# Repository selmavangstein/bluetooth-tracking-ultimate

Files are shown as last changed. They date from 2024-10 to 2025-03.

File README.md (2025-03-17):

# Evaluating Methods for Radio Frequency Based Positioning of Ultimate Frisbee Players

## Abstract
We developed a bluetooth system for tracking ultimate frisbee players. Our project was centered around:
- Exploring different technologies
- Creating and optimizing physical implementations of the best technologies (FTM and UWB), complete with beacons, mounts, and wearables
- Process and analyze the data to make it cleaner and more accurate

This repo contains active, final implementations of data processing and analysis including the data pipeline and the ground truth system, in addition to Arduino and CAD files for the physical implementations. 

### Contributors

| Name | Email |
| --- | --- |
| Cullen Baker | bakerc2@carleton.edu |
| Will Shrestha | shresthaw@carleton.edu |
| Selma Vangstein | vangsteins@carleton.edu |
| Sam Diana  | dianas@carleton.edu |
| Marshall Johnson  | johnsonm@carleton.edu |
| Bemnet Abebayehu  | abebayehub@carleton.edu |

## Contents

- [Abstract](#abstract)
- [How to use](#how-to-use)
- [Project Structure](#project-structure)
- [Data Processing overview](#data-processing-overview)
- [Ground Truth Overview](#ground-truth-overview)
- [Wearable and Beacon Overview](#wearable-and-beacon-overview)
- [Future Work](#future-work)
- [Acknowledgements](#acknowledgements)

## How to use
Simply run `final-postprocessing-pipeline.py` on your desired data by editing the test file names within main, and it will apply the processing steps one piece at a time. 

## Project Structure

To navigate through our codebase, follow the steps below:

1. **Data Creation:**
   Using Code uploaded to a UWB or FTM module from the Arduino IDE, and boosted, powered, held, and added to (accelerometers) with our physical setup, we extract raw data files in `.log` format.

2. **Data Input:**
- These raw data files (in `.log` format) contain distance measurements from the player to each beacon.
- Example files: `rawdataexample.log` (raw data) and `rawdataexample.csv` (processed data).
- All data is stored under the `data/` folder.

3. **Data Cleaning:**
- First, we clean and convert the raw data to a CSV format for easier processing. The folder `data/` contains both ground truth data and processed data files for various days tests were conducted.

4. **Post-Processing Pipeline:**
- Once our data is retrieved and in our desired format, we process the data through various cleaning algorithms in this order:
    - **Distance Correction**
    - **Outlier Removal**
    - **Velocity Clamping**
    - **Smoothing**
    - **Velocity Clamping**
- NOTE: More details for each algorithm above can be found undernearth [Data Processing overview](#data-processing-overview). 
- The `final-postprocessing-pipeline.py` file contains calls to each algorithm above that are sequentially applied to our dataframe. Each step is executed one after the other, and users can rearrange the order of algorithms to fit their needs.

5. **Final Processing:**
- After cleaning, the data is used to estimate player positions using trilateration, which can be found in `final-trilateration.py`.
- The cleaned coordinates are further refined using a Kalman filter. This is implemented in `Final-kalman.py`.
- NOTE: More details for the Kalman filter can be found underneath [Kalman filtering ](#kalman-filtering).

6. **Charts:**
- After the data has been processed, various charts are generated to visualize the effectiveness of each post-processing step. These charts are stored in the `charts/` folder.
- You will find:
    - Plots that show the behavior of the data before and after applying each algorithm.
    - An animation (MP4 video) under the name "streamlit" which visualizes the player’s path during the test.

7. **Frontend:**
- The `frontend.py` file contains a Streamlit-based web interface where you can visualize the results and generate PDF reports from the processed data.

## Data Processing overview
The data processing serves to move from raw testing data files containing distances from player to beacons, to a cleaned and refined dataset containing player coordinates over the duration of the test. 
The raw data generally has low noise levels and lies close to ground truth. It gets noisy whenever something is blocking the line-of-sight between player and beacon. The post processing aims to identify and handle these noisy areas to get accurate coordinate estimates. 
We now aim to walk through the steps in the pipeline. In broad strokes, we start by processing the 1D distance measurements to get rid of noise in the data. The steps in this process are applied in the order listed below, which is what we think is the best order, but the code enables a user to apply these in any order. We then use an alternative trilateration algorithm to determine player coordinates from the position measurements. Finally, we filter the coordinates.

### Distance Correction
We found a systematic overestimate of about 0.8 meters in our raw data, so we subtract this for our dataset. This might be different for different wearables, so in the future we recommend to test each sensor individually, and tune them individually.

### Outlier Removal
This algorithm aims to identify noisy areas and get rid of them. The algorithm is based on identifying deviations from a mean, and is biased towards deleting inflated/deflated measurements, because we notice that the sensors usually overestimates the distance whenever an obstacle is blocking the signal. 
We use a rolling window of 800 ms, and calculate a linear fit in this window. We then mark any window containing a datapoint that deviates more than 0.5 meter from this fitted line as a window containing an outlier. In windows flagged to contain an outlier, we then calculate the median of the window and take the difference of each data point against the median and if it deviates by more than half a meter in either +/- direction, targeting those large spikes, we exclude those points and create a fitted line with the remaining data points. We find that in blocks of noise, there are real data points that still lie close to the ground truth, and the noise causes spikes above this line. We therefore go through a second time in the same manner, calculating the median of the adjusted window, this time only flagging outliers above the fitted line that deviate by more than 0.5 meter in the + direction. We exclude those flagged points and return our fitted line with this newly adjusted window and replace the outliers with nan, unless the window is filled with noise - then we replace them with a point on the fitted line.

### Velocity Clamping
Frisbee players on a field can only move with a max velocity of about 11m/s. We use this to identify remaining outliers in the data. We loop over the data points, and calculate the difference in time and distance from the last valid neighbor. We use this to calculate the average velocity between the data points, and if this is too high, we flag the point as invalid. We keep doing this until no more invalid points are found. We then go through and replace the remaining points with nan.

We will now be left with some small 'floating' clusters of points surrounded by nan. When an obstacle is blocking the signal, we might get several consecutive inflated measurements, and these will not be caught by the velocity clamping. Because these smaller floating groups are probably also noise, we go through and delete them.

We recommend tuning the threshold for what a "small" group of points is, depending on the hardware in use, and where in the pipeline this step is applied. If it is applied on raw data, high variance in noisy areas means that many of these small groups are real values, and we want to be careful with deleting them. However, the outlier removal changes the characteristics of the dataset, and leaves wider bumps rather than narrow spikes in noisy areas, and we can therefore be a lot more aggressive with a higher threshold.

There is a question about whether it is best to simply delete, or try to replace the invalid points. Since we have data from four beacons, and only three are theoretically required to find a coordinate from distance measurements, we decided to delete the points. This way we are not feeding faulty measurements to the trilateration algorithm.

Lastly, note that there is a strong forward bias in this algorithm, meaning that it favours early data points over later ones. If we encounter a wide step representing noise, we might not be able to cut this whole step out. When the data then steps back down to the undisturbed measurements, it will mark the first clean values as invalid, because they have moved too fast away from the noisy step. In the future, it might be possible to also run the algorithm in the other direction, and use some combination of the marked data points to figure out which ones are truly invalid.

### Smoothing
The last thing we do to our distance measurements is to smooth them out. We use an EMA (exponential moving average) algorithm with a window of 15 data points. This window can be tuned in the future, but be cautious about making this window too large, since this will cause the data to lack behind ground truth. The players might be moving erratically, so the smoothing should not be very aggressive.

### Trilateration
The next step is to convert the distance measurements into player coordinates. Regular trilateration is very sensitive to erroneous measurements, so we developed our own algorithm. 
For each set of four distance measurements, we do the following:
- Draw a circle around each beacon corresponding to the measured beacon
- Mark all circle intersections
- Identify the densest cluster of circle intersections
- Find the centroid of this densest cluster. This is the final position coordinate.
- Use the distance between the coordinate and each circle to calculate a measurement error
This algorithm is more robust than regular trilateration - if one beacon measurement is off, it will not affect the final coordinate. We will also still be able to come up with a coordinate if some data is completely missing. 
We do this for each timestamp, and finally plot a player trace with the coordinates.

### Kalman Filtering
We now apply a Kalman filter to the coordinate dataset. We use a 6-state constant acceleration model, with (x,y)-position coordinates as the only measurement, and velocity and acceleration as hidden variables. 
A Kalman filter is essentially a cycle of predictions, measurements and weighted averages. The filter uses a constant acceleration model to use the previous measurement to predict what the next position will be. It then takes in the actual measured coordinates, and uses the uncertainties of the measurement and prediction to take a weighted average between the two, and this gives us the filtered coordinate. 
The repo we used, along with some really thorough documentation, can be found here: https://github.com/rlabbe/Kalman-and-Bayesian-Filters-in-Python

We also added some additional steps to the filter cycle:

#### Dynamic filter adjustment
We used the error estimation from the trilateration algorithm to dynamically adjust the filter as we go. If the coordinate error is too high, we inflated the measurement uncertainty, essentially telling the filter to mostly disregard the measurement, and trust the prediction instead.

#### Velocity and acceleration clamping
We then added a 2D-version of the velocity clamping from above. This time, we did not want gaps in our data, so whenever an invalid point was detected, we replaced it with a new point in the same direction, but closer to its neighbor. We also added another layer to this clamping, taking the current acceleration magnitude into account. This magnitude was calculated from the data we get from the accelerometer.

#### RTS Smoothing
The final step is to apply RTS Smoothing. This smoothing algorithm is implemented for us by the Kalman package. It work in essentially the same way as the Kalman filter, except for the fact that it runs backwards. This means that it uses the future datapoints to predict the previous ones, balancing out the forward bias the Kalman filter introduced.

## Ground Truth Overview
We recorded videos of our testing. Each video begins by looking at a phone that is on time.gov displaying the exact time. This allows us to match where the testing subject is in the video to the time of the outputted data. 

We used a couple different systems of actually obtaining the ground truth data for each timestamp, all of which are centered around Google Sheets and the distance between cones and beacons. One method is to assign grid coordinates to the cones, then use the distance between two points formula for each (works best when the path walked varies). Another is to precalculate the distance between each cone and each beacon and then copy it for each additional reading (works best when the path walked stays the same)

Our ground truth system is fundamentally imperfect as, since we have humans inputting ground truth data that has been matched to the second, each ground truth reading can vary by up to one second.

The ground truth data is then compared to the raw data and the processed data using GroundTruthPipeline.py.

The videos, Google Sheets files, raw data, and outputted ground truth can all be found in this repository. 

## Wearable and Beacon overview
We designed many different models of wearables and beacons for FTM and UWB, designed to fill different needs, including:
- comfort
- convenience
- protection
- minimal signal obstruction

We fully created and assembled numerous models.

## Future Work
In the future, we plan to implement multi-player functionality, as the system currently supports only single-player tracking. Additionally, we aim to enhance the frontend to include live statistical analysis and track more player metrics beyond just location. We also plan to improve the data processing algorithms, potentially utilizing machine learning-based outlier detection for more thorough and effective noise removal. Furthermore, we will hope to explore alternative hardware mechanisms and improve existing ones, such as FTM and UWB.

## Acknowledgements
We would like to thank our advisor Eric Alexander for all of the patience and help given to us throughout these past two terms. He has been instrumental in guiding us in completing our project. We would also like to thank Aaron Heidgerken-Greene for his assistance and help within the makerspace and constructions of our hardware. Please feel free to reach out to Eric Alexander for any questions or wants to work on this.

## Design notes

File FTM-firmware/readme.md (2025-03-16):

# FTM software
FTM was one of the first positioning technologies we seriously considered. This setup consists of beacons, a wearable, and a recorder beacon. The wearable device iterates through each of the beacons, connecting and taking an FTM measurement, before sending this and acceleration data via espnow to be recorded. 

## Required materials
For our implementation of FTM positioning, we're making use of 6x xiao esp32s3 boards. 4 will act as beacons, 1 will act as a wearable, and 1 will act as a "recorder beacon". This firmware is likely compatible with any esp32 that supports FTM ranging, but this has not been confirmed.

## Flashing boards
Before getting started, make sure you install the necessary dependencies via the Arduino IDE. You'll need Wire, adafruit Sensor, and adafruit ADXL345_U.

Start by flashing the recorder beacon board; you'll need to make sure that you acquire the MAC address for this board, or else the wearable will not be able to communicate with it. This device will send data it receives via a serial-usb connection.

Your wearable board will simply need to be flashed with the provided sketch, after modifying the espNow receiver address. See the recorder_beacon sketch for more details on the mac address retrieval process. Please also ensure that the ADXL345 accelerometer is wired correctly, as a failure to do so can cause unpredictable issues.

To flash beacons, make sure that you change the beacon's address to one of the 4 provided ANCHOD_ADD values (such that there is one of each). Note that if you do change the address of an anchor, you'll also need to modify the switch found in the wearable.

## Common Issues
Make sure that you've enabled USE-CDC-ONBOOT (in the arduino ide) for any device you intend to print over serial. 

Make sure that you have the correct board selected, otherwise pin assignment/other issues might occur.

Ensure that your accelerometer is producing values; try using one of Adafruit's example sketches. Failure to do so can cause issues down the line.

Make sure that you have the correct MAC address of your recorder beacon, and have correctly input this into the wearable's firmware. Otherwise, the connection will fail and you won't be able to collect data.

Make sure each beacon has a unique network name, and that any changes you make to your beacon names are also reflected in your wearable firmware.

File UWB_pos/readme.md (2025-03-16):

# UWB software
For its accuracy and sampling rate, UWB represented one of the best options we found thus far. For our experiments, we utilized dw1000 boards. By default, this software also utilizes espnow to extract data. The recorder beacon software is identical for FTM, thus the sketch found in the FTM-firmware can be used.

## Required materials
For our implementation of UWB positioning, we're making use of 5xMakerfabs UWB-esp32 boards and another that supports espNow. 4 will act as beacons(to use UWB terminology, anchor), 1 will act as a wearable (tag), and 1 will act as a recorder beacon. You will also need an ADXL345 accelerometer, connected to the default i2c pins of your board.

## Flashing boards
Before getting started, make sure you install the necessary dependencies via the Arduino IDE. Notably, we built using makerfabs provided driver (based off the original, Thotro driver)

Your wearable board will simply need to be flashed with the provided sketch, after modifying the espNow receiver address. See the recorder_beacon sketch in FTM-firmware for more details on the mac address retrieval process. Please also ensure that the ADXL345 accelerometer is wired correctly, as a failure to do so can cause unpredictable issues.

To flash beacons, make sure that you change the beacon's address to one of the 4 provided ANCHOD_ADD values (such that there is one of each). Note that if you do change the address of an anchor, you'll also need to modify the switch found in the wearable.

## Common issues
Make sure that you've enabled USE-CDC-ONBOOT (in the arduino ide) for any device you intend to print over serial. 

Make sure that you have the correct board selected, otherwise pin assignment/other issues might occur. The makerfabs boards just work with the "ESP32 Dev Module" setting.

Ensure that your accelerometer is producing values; try using one of Adafruit's example sketches. Failure to do so can cause issues down the line.

Make sure that you have the correct MAC address of your recorder beacon, and have correctly input this into the wearable's firmware. Otherwise, the connection will fail and you won't be able to collect data.

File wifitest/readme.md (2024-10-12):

A simple test program for the s2 (although should be pretty universally compatible). Connects to my phone, and prints current signal level over serial.

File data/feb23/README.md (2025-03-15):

# Descriptions for Tests from February 23

## aroundsquare
In this test, we had a tester wear the UWB wearable on their head and walk inside the rec between adjacent cones in a 3x3 grid of cones that are each 3 meters apart.

### aroundsquare-groundtruth.csv
Ground truth data.

### aroundsquare-uwb.csv
Data from the UWB wearable.

## diagonals
In this test, we used the same setup as the previous test but the tester walked to diagonal cones as well as adjacent cones

### diagonals-groundtruth.csv
Ground truth data.

### diagonals-uwb.csv
Data from the UWB wearable.

## Test locations in coordinates (m)
Beacon 1: (0, 0)
Beacon 2: (28.7, 0)
Beacon 3: (28.7, 25.7)
Beacon 4: (0, 25.7)
Top left cone: (11.35, 15.85)
Top center cone: (14.35, 15.85)
Top right cone: (17.35, 15.85)
Middle left cone: (11.35, 12.85)
Middle center cone: (14.35, 12.85)
Middle right cone: (17.35, 12.85)
Bottom left cone: (11.35, 9.85)
Bottom center cone: (14.35, 9.85)
Bottom right cone: (17.35, 9.85)

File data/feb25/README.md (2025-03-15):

# Descriptions for Tests from February 25

## abovehead
In this test, we had a tester hold the wearable above their head and walk inside the rec between adjacent and diagonal cones in a 3x3 grid of cones that are each 3 meters apart.

### abovehead-groundtruth.csv
Ground truth data.

### abovehead-uwb.csv
Data from the UWB wearable.

## blockingbeacon
In this test, we had a tester wear the UWB wearable on their head and walk inside the rec between adjacent cones in a 3x3 grid of cones that are each 3 meters apart.
We also had another person standing in front of Beacon 1 as an obstacle.

### blockingbeacon-groundtruth.csv
Ground truth data.

### blockingbeacon-uwb.csv
Data from the UWB wearable.

## markingtest
In this test, we had a tester wear the UWB wearable on their head and walk inside the rec between adjacent cones in a 3x3 grid of cones that are each 3 meters apart.
We also had another person following the tester closely and staying between the wearable and Beacon 1 as an obstacle.

### markingtest-groundtruth.csv
Ground truth data.

### markingtest-uwb.csv
Data from the UWB wearable.

## Test locations in coordinates (m)
Beacon 1: (0, 0)
Beacon 2: (28.7, 0)
Beacon 3: (28.7, 25.7)
Beacon 4: (0, 25.7)
Top left cone: (11.35, 15.85)
Top center cone: (14.35, 15.85)
Top right cone: (17.35, 15.85)
Middle left cone: (11.35, 12.85)
Middle center cone: (14.35, 12.85)
Middle right cone: (17.35, 12.85)
Bottom left cone: (11.35, 9.85)
Bottom center cone: (14.35, 9.85)
Bottom right cone: (17.35, 9.85)

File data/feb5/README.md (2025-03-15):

# Descriptions for Tests from February 5

## obstacletest
In this test, we had a tester hold the UWB wearable and walk inside the rec from cone to cone in a 3x3 grid of cones that are each 3 meters apart. We also had someone stand
directly in front of Beacon 1 to act as an obstacle.

### obstacletest-groundtruth.csv
Ground truth data.

### obstacletest-uwb.csv
Data from the UWB wearable.

## Test locations in coordinates (m)
Beacon 1: (0, 0)
Beacon 2: (12, 0)
Beacon 3: (0, 18)
Beacon 4: (12, 18)
Top left cone: (3, 12)
Top center cone: (6, 12)
Top right cone: (9, 12)
Middle left cone: (3, 9)
Middle center cone: (6, 9)
Middle right cone: (9, 9)
Bottom left cone: (3, 6)
Bottom center cone: (6, 6)
Bottom right cone: (9, 6)

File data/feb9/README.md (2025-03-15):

# Descriptions for Tests from February 9

## linerectangle
In this test, we had a tester hold the FTM and UWB wearables and walk on the Anderson lawn in a straight line for 40 meters and then back, with additional turns on the way back
that form 5m x 10m rectangle in the middle of the straight line. Cones were placed every 5 meters on the 40 meter straight line and at each corner of the rectangle.

### linerectangle-ftm.csv
Data from the FTM wearable.

### linerectangle-groundtruth.csv
Ground truth data.

### linerectangle-uwb.csv
Data from the UWB wearable.

## Test locations in coordinates (m)
Beacon 1: (20, 0)
Beacon 2: (0, 0)
Beacon 3: (0, 40)
Beacon 4: (20, 40)
Straight line start: (10, 0)
Straight line far end: (10, 40)
Rectangle corner 1: (5, 20)
Rectangle corner 2: (5, 15)
Rectangle corner 3: (15, 15)
Rectangle corner 4: (15, 20)

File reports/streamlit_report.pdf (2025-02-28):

## Bluetooth Tracking Report

RF Positioning Report

February 27, 2025

1

## 1 1D b1d_distance

Figure 1: b1d Distance Over Time

2

## 2 1D b2d_distance

Figure 2: b2d Distance Over Time

3

## 3 1D b3d_distance

Figure 3: b3d Distance Over Time

4

## 4 1D b4d_distance

Figure 4: b4d Distance Over Time

5

## 5 streamlit

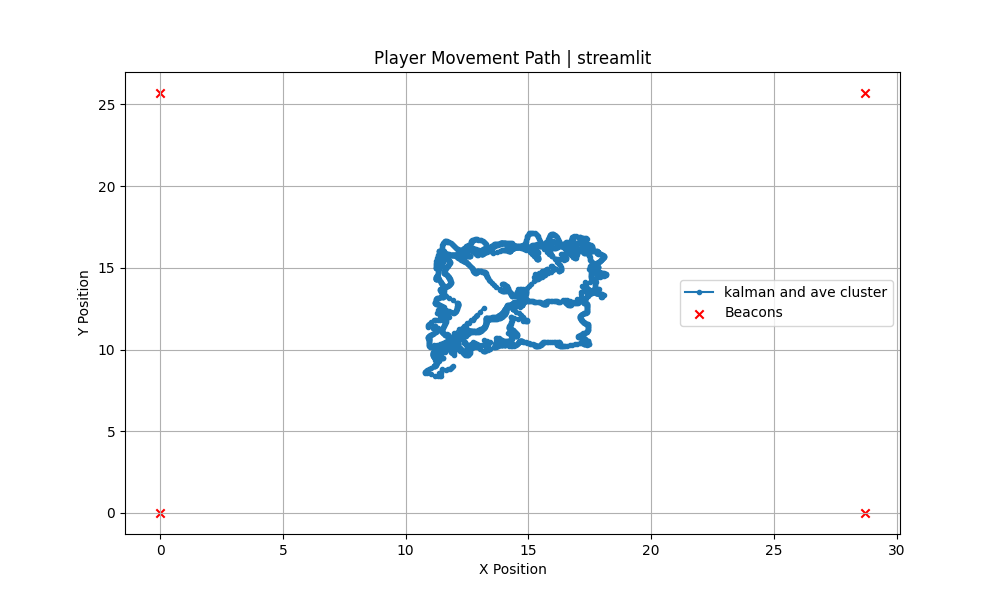
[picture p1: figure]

Figure 5: Final Player Movement Path

6

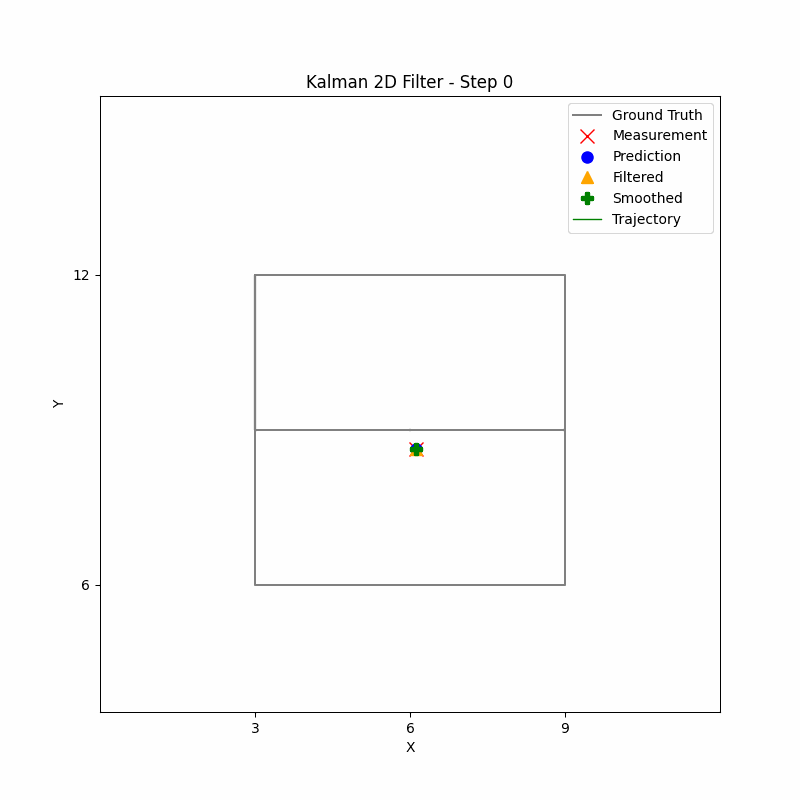
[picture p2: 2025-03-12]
kalman_animation_overhead.gif

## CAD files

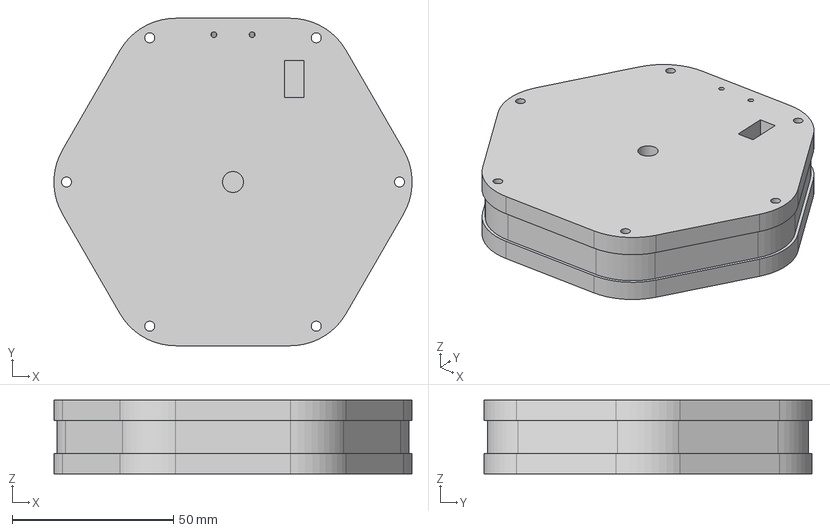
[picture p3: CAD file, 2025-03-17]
Wearables_and_Mounts/FTM_Mounts/FTM_beacon.step
111.1 x 101.6 x 22.9 mm
BOSS-EXTRUDE14_8_
BOSS-EXTRUDE7_4_
BOSS-EXTRUDE7_3_
BOSS-EXTRUDE14_4_
BOSS-EXTRUDE14_2_
BOSS-EXTRUDE14_11_
BOSS-EXTRUDE7_7_
BOSS-EXTRUDE14_9_
BOSS-EXTRUDE14_3_
BOSS-EXTRUDE14_7_
MIRROR2
BOSS-EXTRUDE14_5_
BOSS-EXTRUDE14_12_
BOSS-EXTRUDE7_8_
BOSS-EXTRUDE7_1_
BOSS-EXTRUDE14_10_
BOSS-EXTRUDE7_9_
BOSS-EXTRUDE14_6_
BOSS-EXTRUDE14_1_
BOSS-EXTRUDE7_6_
BOSS-EXTRUDE7_2_
CUT-EXTRUDE5
BOSS-EXTRUDE7_5_
Shield
Pins x 2
U.FL-R-SMT-1_10_ v1

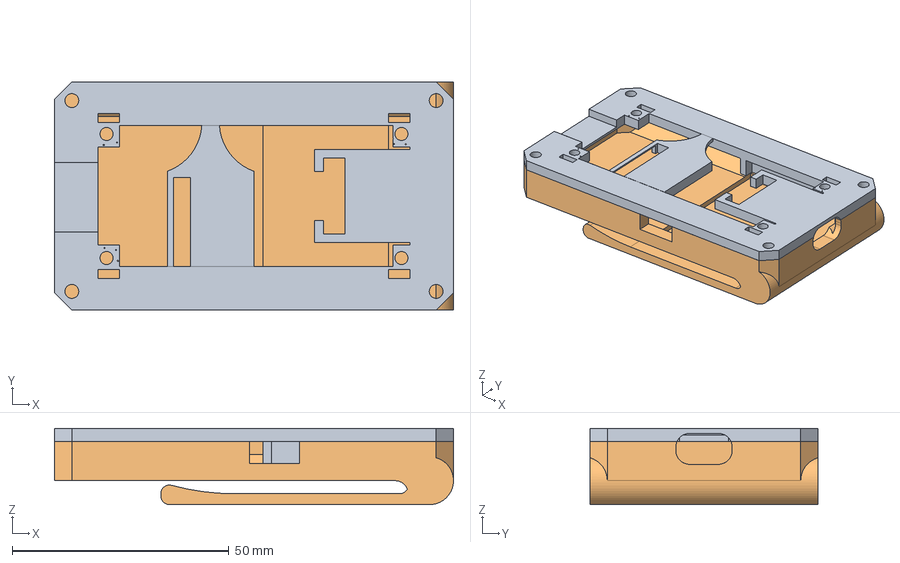
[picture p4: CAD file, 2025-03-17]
Wearables_and_Mounts/UWB_Mounts/UWB_clip_mount.step
92.0 x 52.6 x 17.6 mm
mounting layer
back plate

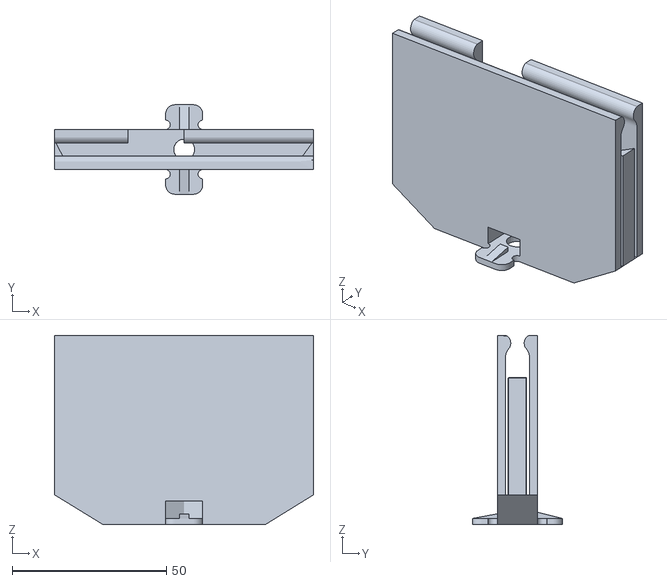
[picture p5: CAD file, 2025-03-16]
Wearables_and_Mounts/UWB_Mounts/shrunkpiece1.stl
83.9 x 29.0 x 61.3

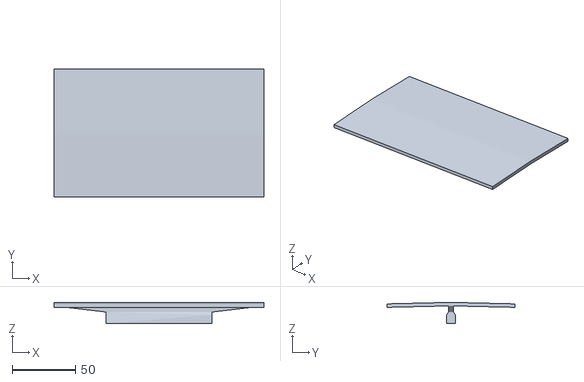
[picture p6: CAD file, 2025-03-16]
Wearables_and_Mounts/UWB_Mounts/piece1short.stl
166.5 x 101.2 x 16.8

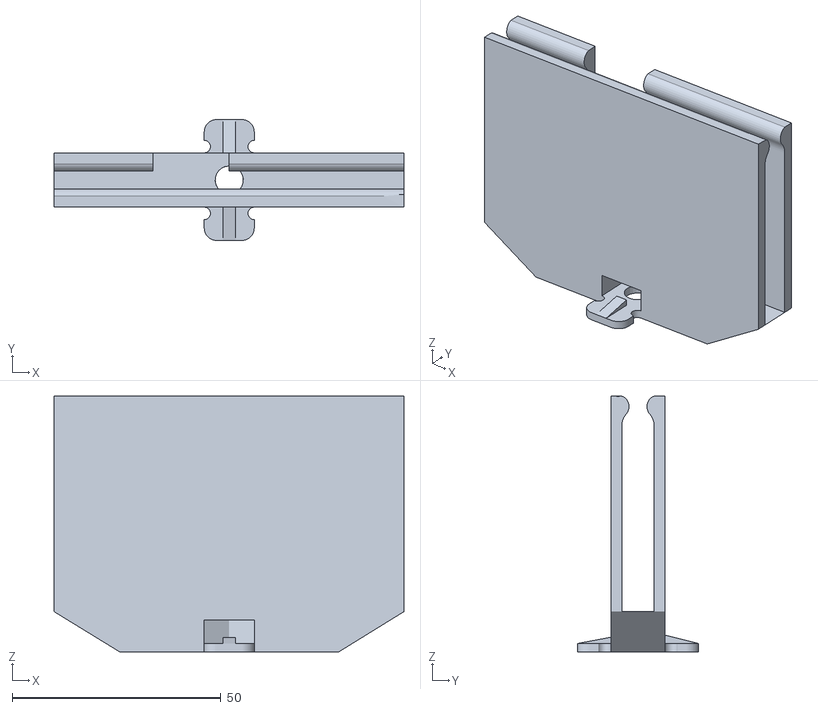
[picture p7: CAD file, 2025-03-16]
Wearables_and_Mounts/UWB_Mounts/piece2short.stl
83.9 x 29.0 x 61.3

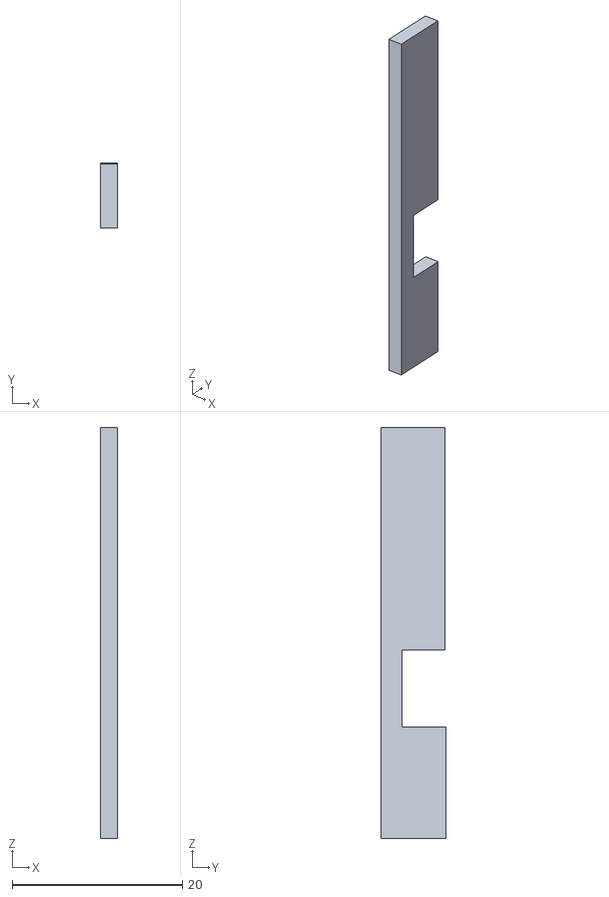
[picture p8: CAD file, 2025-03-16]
Wearables_and_Mounts/UWB_Mounts/Piece2taller.stl
2.00 x 7.59 x 48.3

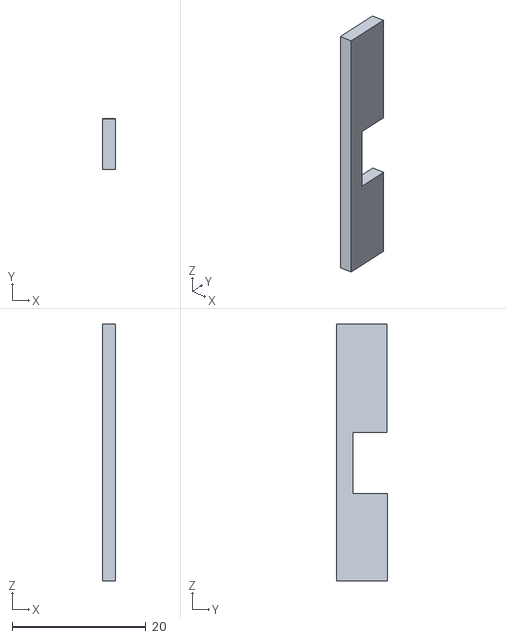
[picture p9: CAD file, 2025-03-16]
Wearables_and_Mounts/UWB_Mounts/piece3short.stl
2.00 x 7.59 x 38.4

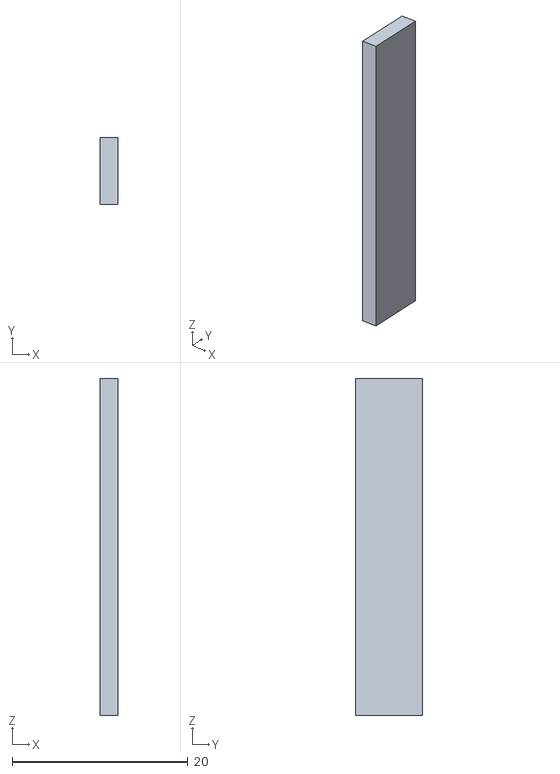
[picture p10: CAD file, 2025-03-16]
Wearables_and_Mounts/UWB_Mounts/piece4short.stl
2.00 x 7.59 x 38.4

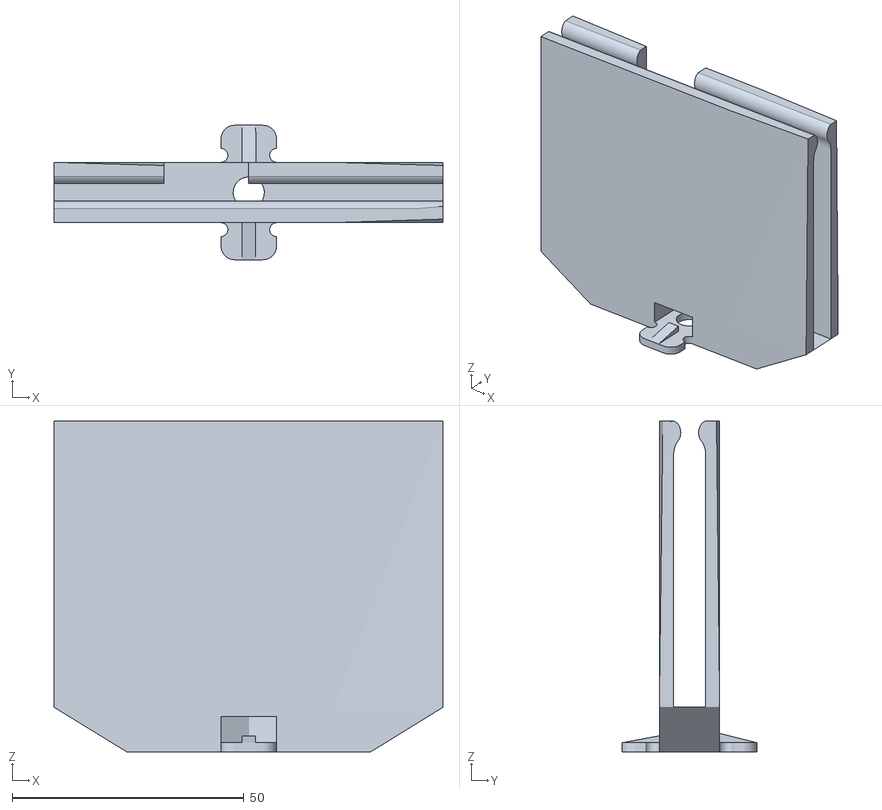
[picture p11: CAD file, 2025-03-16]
Wearables_and_Mounts/UWB_Mounts/shrunkbody.stl
83.9 x 29.0 x 71.4

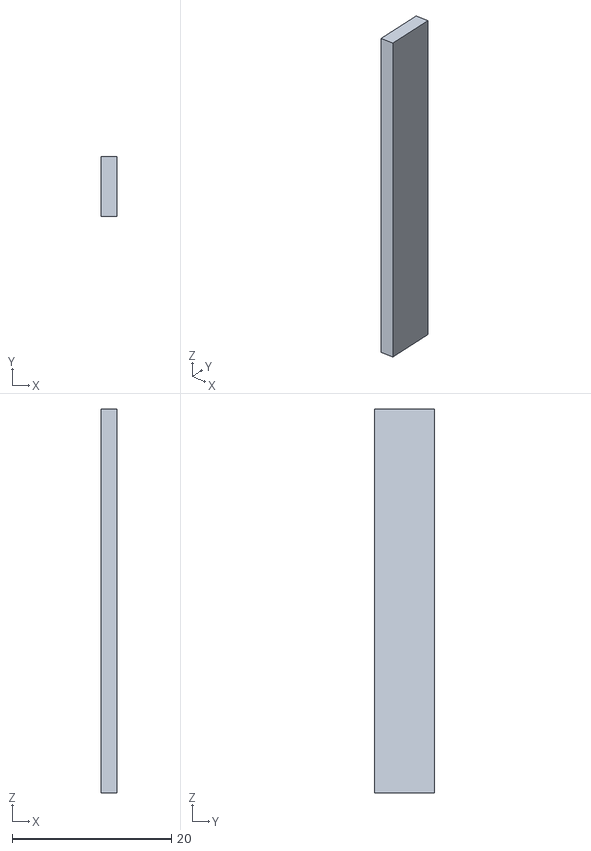
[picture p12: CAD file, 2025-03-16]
Wearables_and_Mounts/UWB_Mounts/Piece3taller.stl
2.00 x 7.59 x 48.2

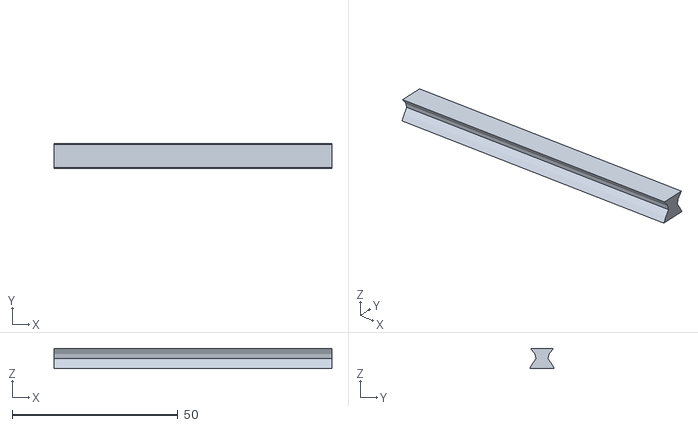
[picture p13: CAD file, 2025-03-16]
Wearables_and_Mounts/UWB_Mounts/shrunkpiece2.stl
83.9 x 7.46 x 6.07

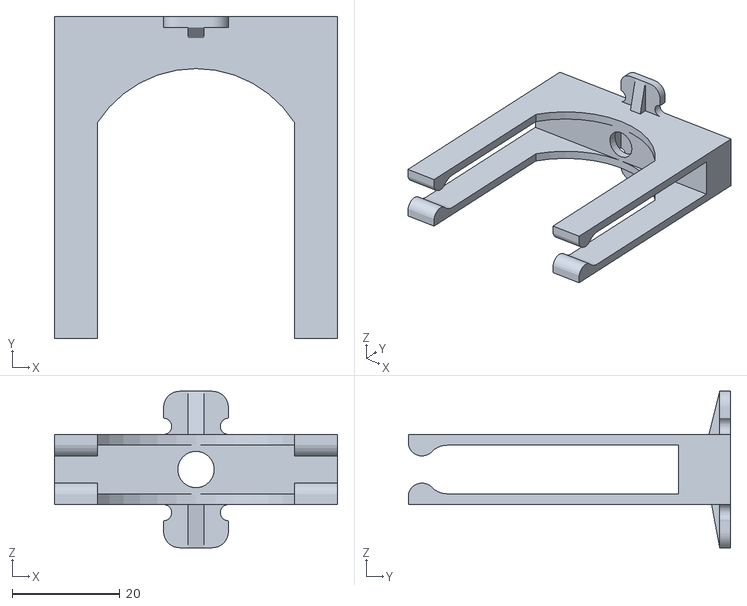
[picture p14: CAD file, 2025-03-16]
Wearables_and_Mounts/UWB_Mounts/iPod_Tripod_Mount_repaired.stl
52.5 x 59.6 x 29.0

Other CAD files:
Wearables_and_Mounts/UWB_Mounts/Piece1taller.stl

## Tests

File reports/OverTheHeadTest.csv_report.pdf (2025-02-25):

## Bluetooth Tracking Report

OverTheHeadTest.csv

February 21, 2025

1

## 1 1D b1d_distance

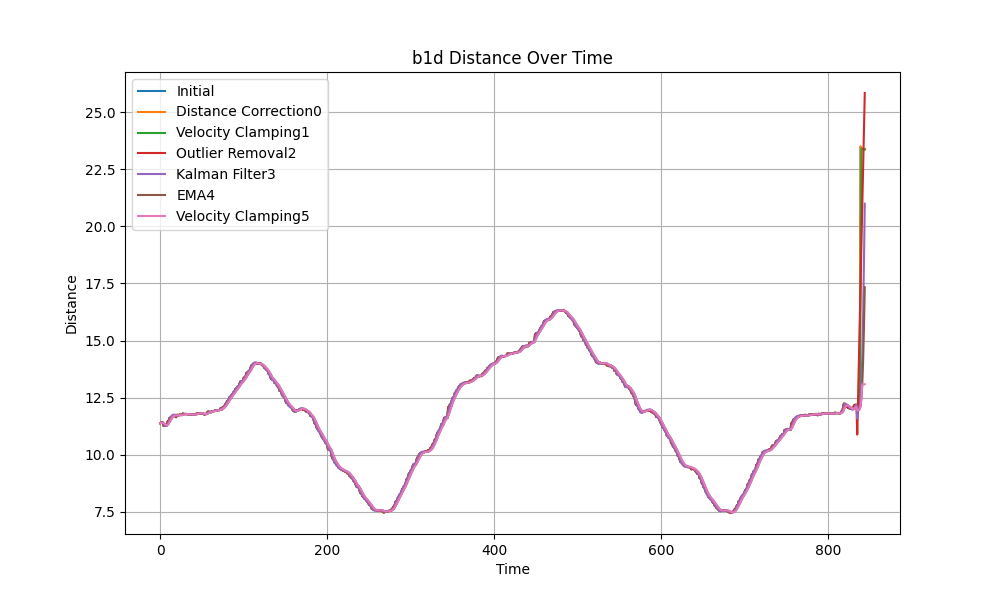
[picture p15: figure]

Figure 1: b1d Distance Over Time

2

## 2 1D b2d_distance

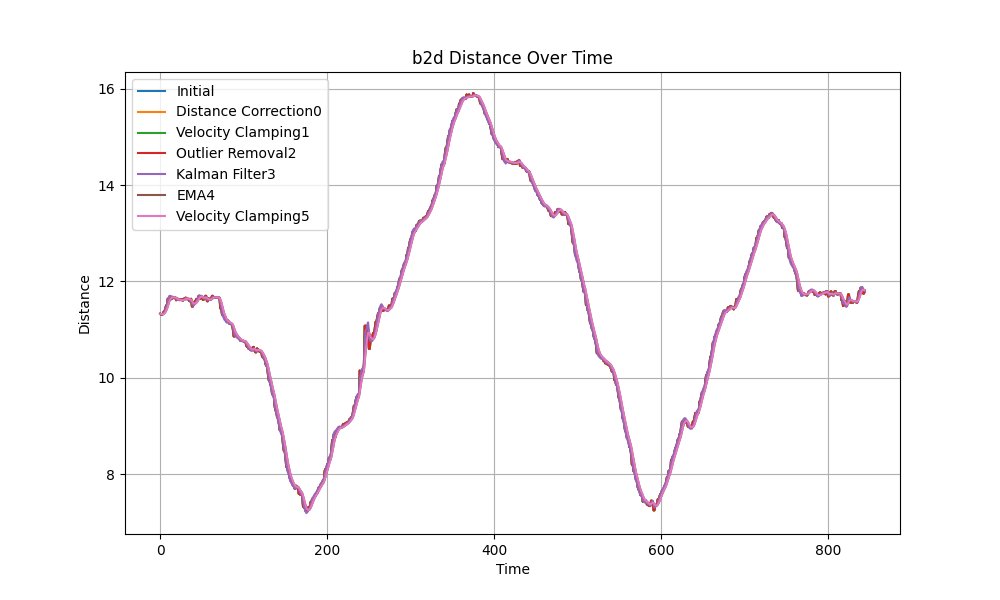
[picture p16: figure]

Figure 2: b2d Distance Over Time

3

## 3 1D b3d_distance

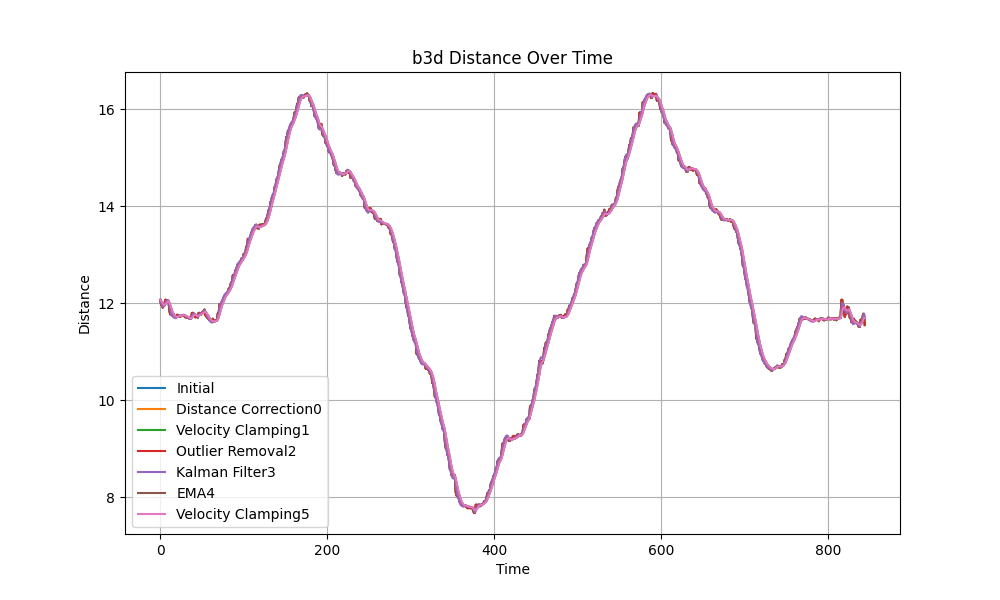
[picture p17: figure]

Figure 3: b3d Distance Over Time

4

## 4 1D b4d_distance

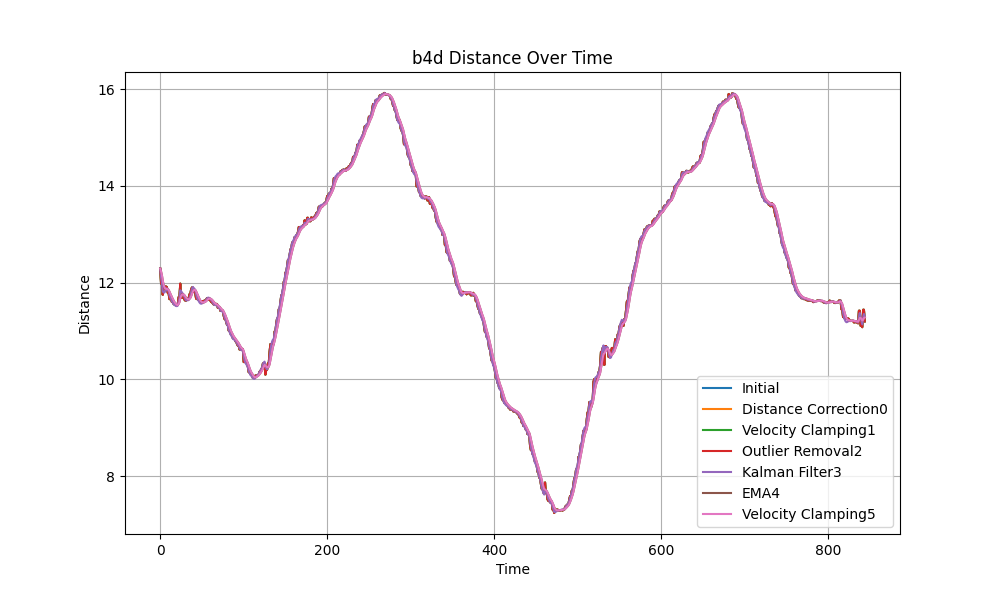
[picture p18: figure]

Figure 4: b4d Distance Over Time

5

5 Initial - Ground Truth Comp.

Anchor 1: MAE=nan m, RMSE=nan m
Anchor 2: MAE=nan m, RMSE=nan m
Anchor 3: MAE=nan m, RMSE=nan m Anchor 4: MAE=nan m, RMSE=nan m

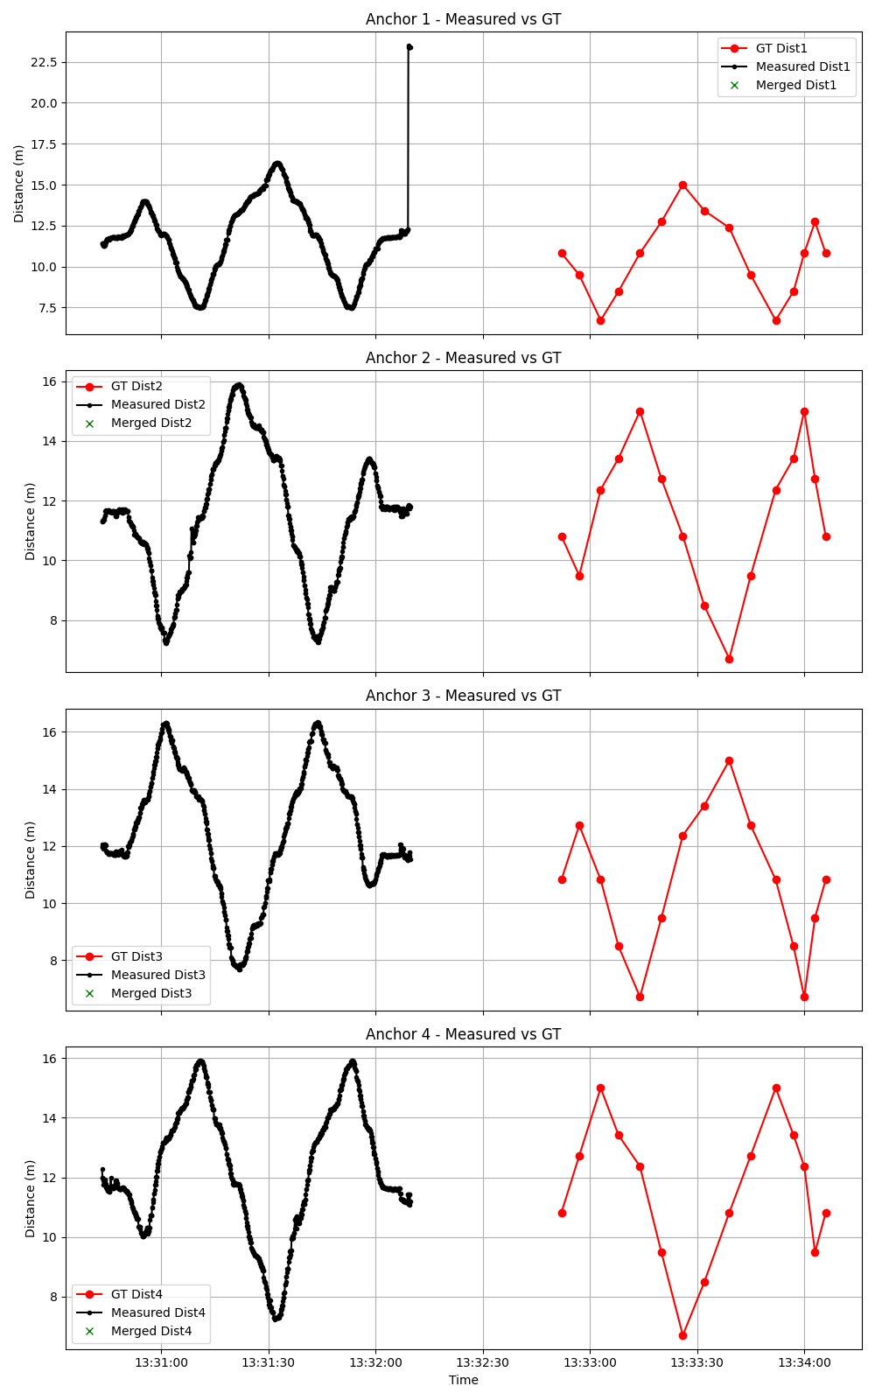
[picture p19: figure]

Figure 5: Initial Measured vs GT Distance

6

6 Distance Correction0 - Ground Truth Comp.

Anchor 1: MAE=nan m, RMSE=nan m
Anchor 2: MAE=nan m, RMSE=nan m
Anchor 3: MAE=nan m, RMSE=nan m Anchor 4: MAE=nan m, RMSE=nan m

Figure 6: Distance Correction0 Measured vs GT Distance

7

7 Velocity Clamping1 - Ground Truth Comp.

Anchor 1: MAE=nan m, RMSE=nan m
Anchor 2: MAE=nan m, RMSE=nan m
Anchor 3: MAE=nan m, RMSE=nan m Anchor 4: MAE=nan m, RMSE=nan m

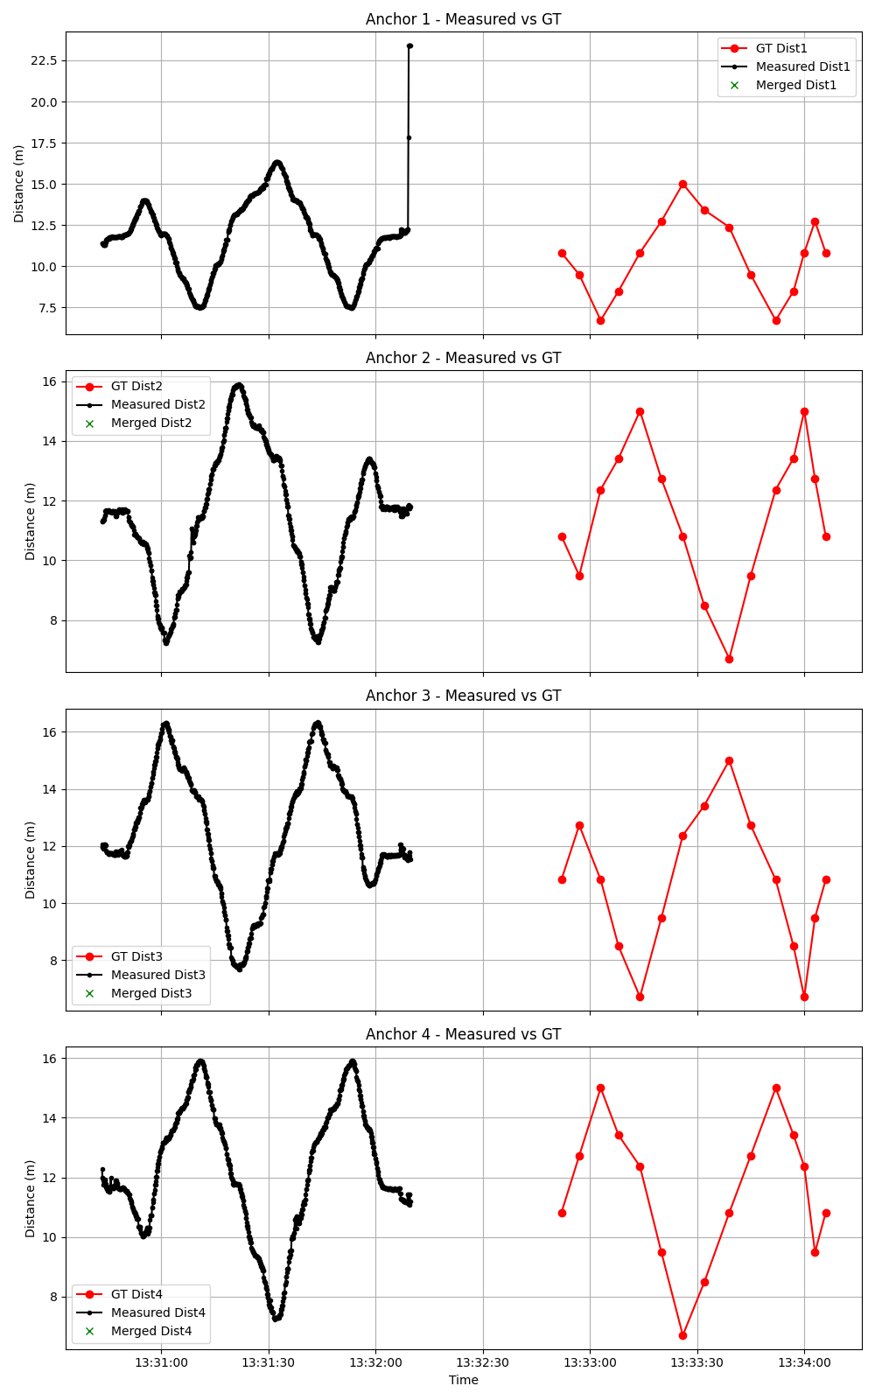
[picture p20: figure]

Figure 7: Velocity Clamping1 Measured vs GT Distance

8

8 Outlier Removal2 - Ground Truth Comp.

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

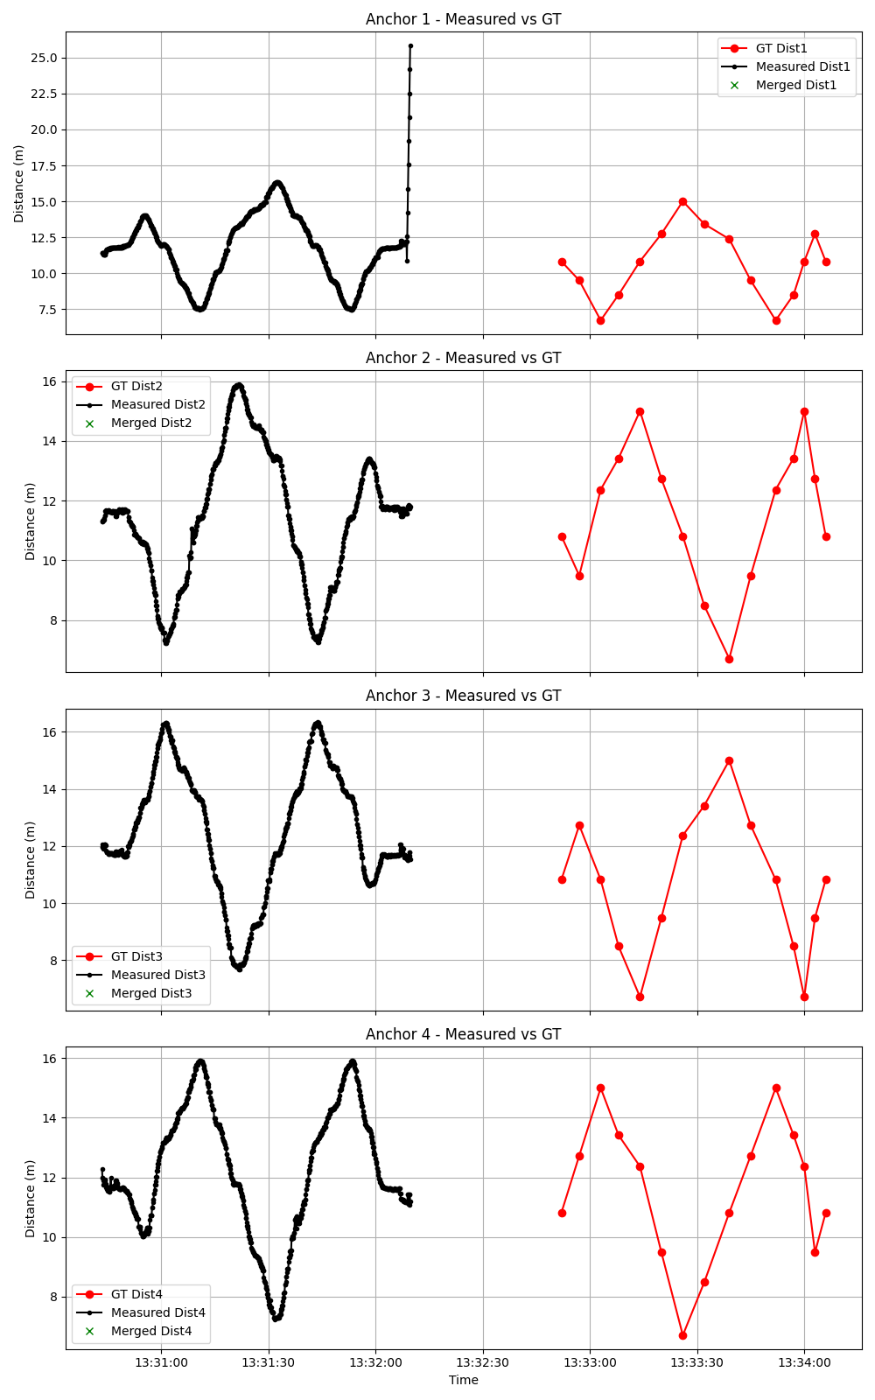
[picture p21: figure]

Figure 8: Outlier Removal2 Measured vs GT Distance

9

9 Kalman Filter3 - Ground Truth Comp.

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

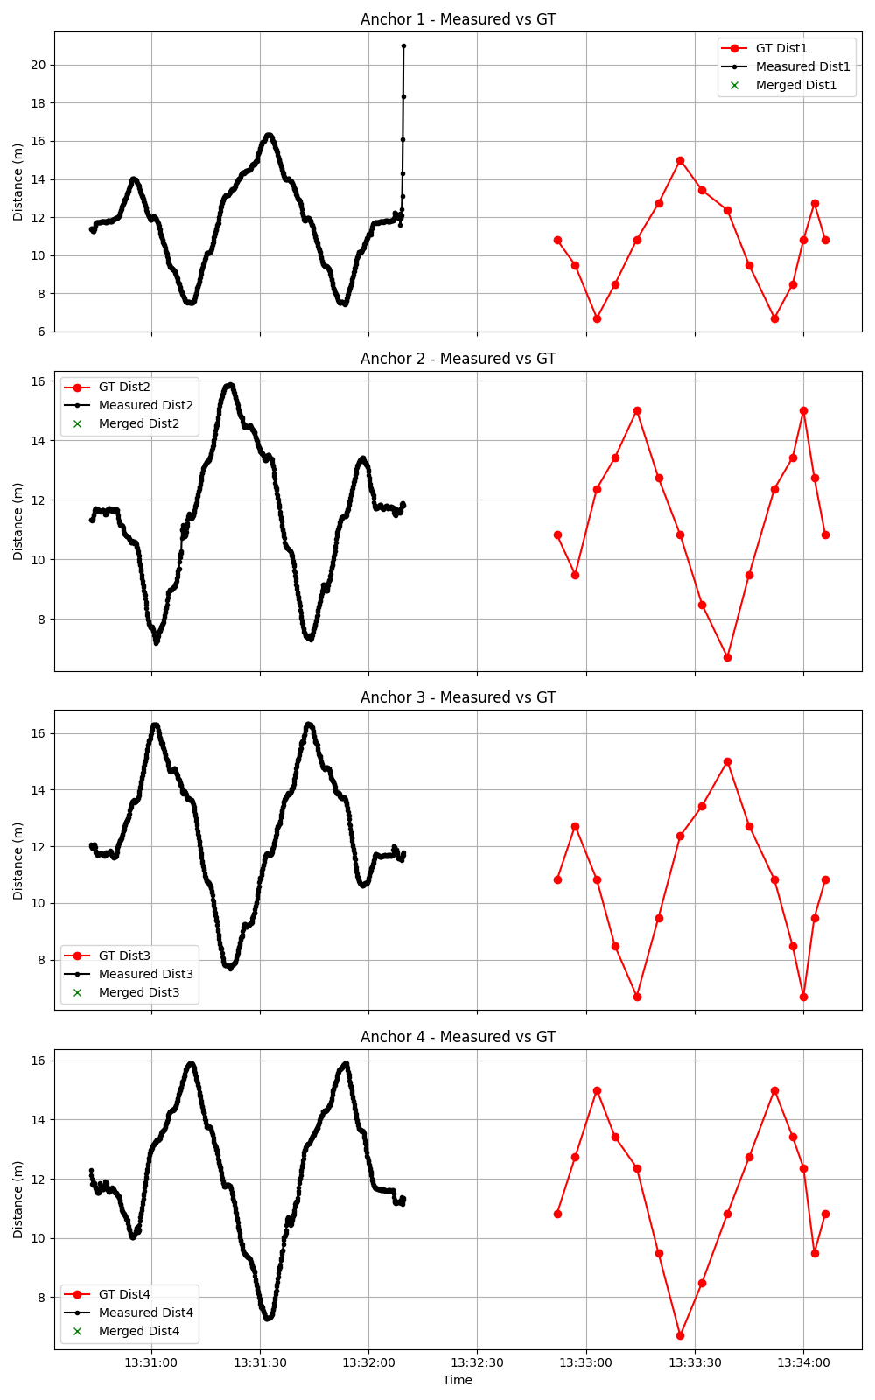
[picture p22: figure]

Figure 9: Kalman Filter3 Measured vs GT Distance

10

10 EMA4 - Ground Truth Comp.

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

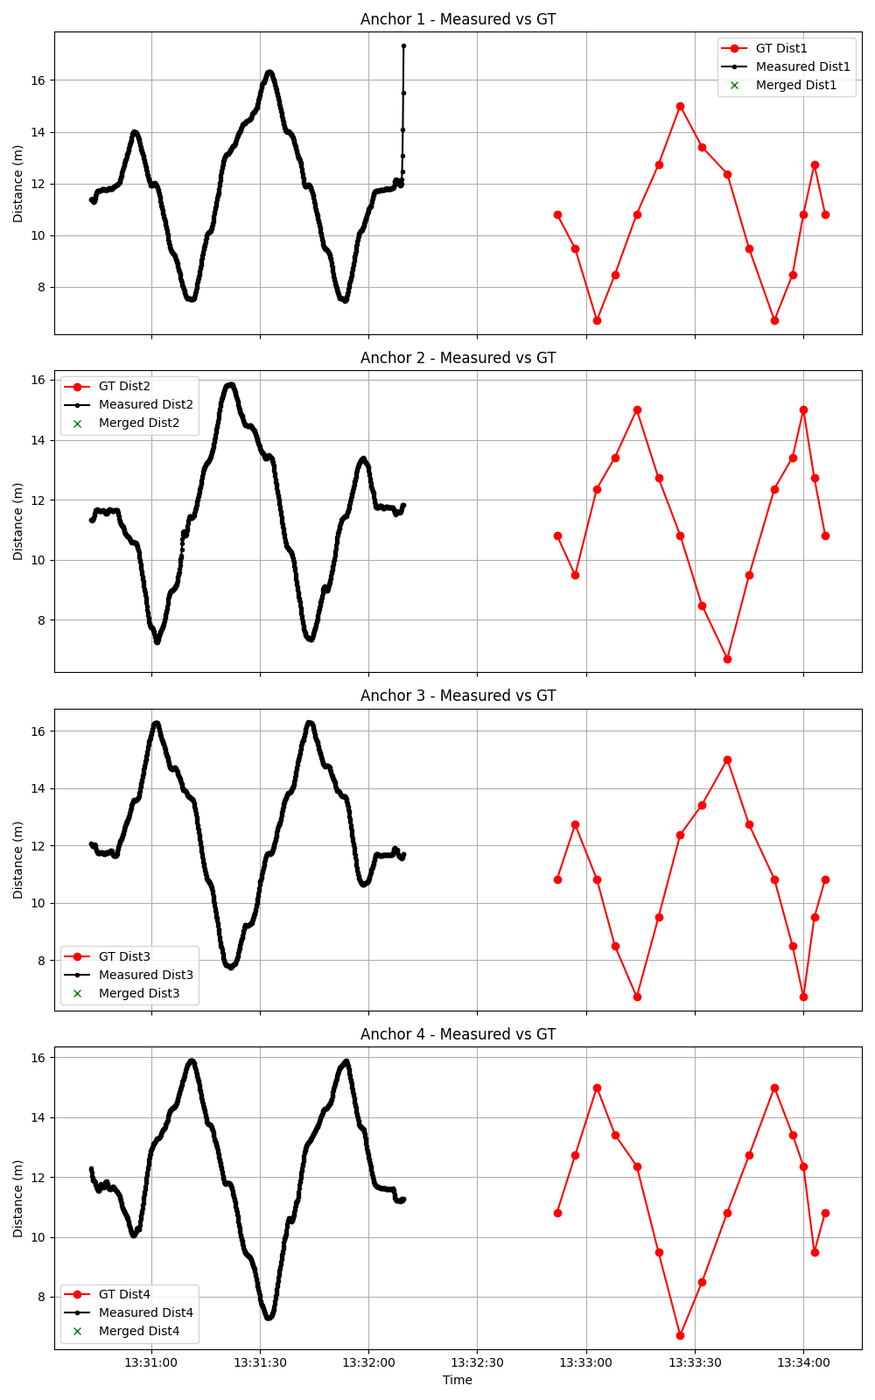
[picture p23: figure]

Figure 10: EMA4 Measured vs GT Distance

11

11 Velocity Clamping5 - Ground Truth Comp.

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

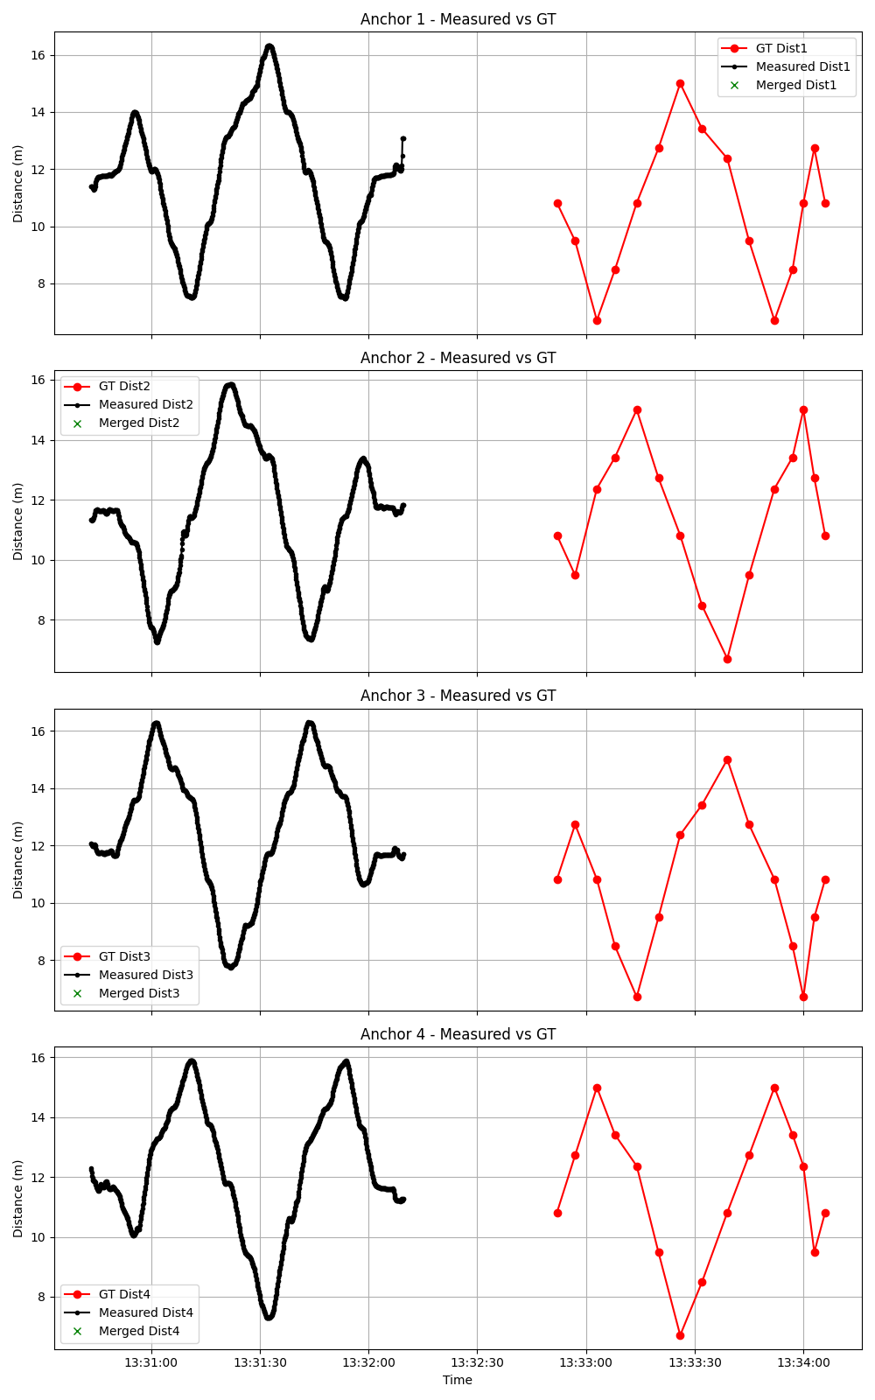
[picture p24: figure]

Figure 11: Velocity Clamping5 Measured vs GT Distance

12

## 12 Ground Truth


Figure 12: Ground Truth Player Movement Path

13

## 13 Initial


Figure 13: Player Movement Path

14

## 14 Distance Correction0


Figure 14: Player Movement Path

15

## 15 Velocity Clamping1


Figure 15: Player Movement Path

16

## 16 Outlier Removal2


Figure 16: Player Movement Path

17

## 17 Kalman Filter3


Figure 17: Player Movement Path

18

## 18 EMA4


Figure 18: Player Movement Path

19

## 19 Velocity Clamping5


Figure 19: Player Movement Path

20

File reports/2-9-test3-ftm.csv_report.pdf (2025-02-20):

## Bluetooth Tracking Report

feb9/2-9-test3-ftm.csv

February 19, 2025

1

## 1 1D b1d_distance


Figure 1: b1d Distance Over Time

2

## 2 1D b2d_distance


Figure 2: b2d Distance Over Time

3

## 3 1D b3d_distance


Figure 3: b3d Distance Over Time

4

## 4 1D b4d_distance


Figure 4: b4d Distance Over Time

5

5 Initial - Ground Truth Comp.

Anchor 1: MAE=5.807 m, RMSE=16.228 m Anchor 2: MAE=7.066 m, RMSE=11.568 m Anchor 3: MAE=6.293 m, RMSE=11.253 m Anchor 4: MAE=6.745 m, RMSE=9.788 m


Figure 5: Initial Measured vs GT Distance

6

6 Distance Correction0 - Ground Truth Comp.

Anchor 1: MAE=5.007 m, RMSE=15.960 m
Anchor 2: MAE=6.287 m, RMSE=11.097 m
Anchor 3: MAE=5.493 m, RMSE=10.826 m Anchor 4: MAE=6.015 m, RMSE=9.275 m


Figure 6: Distance Correction0 Measured vs GT Distance

7

7 Velocity Clamping1 - Ground Truth Comp.

Anchor 1: MAE=1.833 m, RMSE=2.115 m
Anchor 2: MAE=7.067 m, RMSE=11.627 m
Anchor 3: MAE=3.638 m, RMSE=6.016 m Anchor 4: MAE=5.341 m, RMSE=6.720 m


Figure 7: Velocity Clamping1 Measured vs GT Distance

8

8 Outlier Removal2 - Ground Truth Comp.

Anchor 1: MAE=1.654 m, RMSE=1.980 m
Anchor 2: MAE=5.205 m, RMSE=9.048 m
Anchor 3: MAE=3.160 m, RMSE=4.786 m Anchor 4: MAE=5.356 m, RMSE=6.604 m


Figure 8: Outlier Removal2 Measured vs GT Distance

9

9 Kalman Filter3 - Ground Truth Comp.

Anchor 1: MAE=1.619 m, RMSE=1.946 m
Anchor 2: MAE=5.222 m, RMSE=9.045 m
Anchor 3: MAE=3.156 m, RMSE=4.736 m Anchor 4: MAE=5.295 m, RMSE=6.579 m


Figure 9: Kalman Filter3 Measured vs GT Distance

10

10 EMA4 - Ground Truth Comp.

Anchor 1: MAE=1.633 m, RMSE=2.072 m
Anchor 2: MAE=5.714 m, RMSE=10.043 m
Anchor 3: MAE=3.208 m, RMSE=4.739 m Anchor 4: MAE=5.201 m, RMSE=6.703 m


Figure 10: EMA4 Measured vs GT Distance

11

11 Velocity Clamping5 - Ground Truth Comp.

Anchor 1: MAE=1.633 m, RMSE=2.072 m
Anchor 2: MAE=5.714 m, RMSE=10.043 m
Anchor 3: MAE=3.208 m, RMSE=4.739 m Anchor 4: MAE=5.201 m, RMSE=6.703 m


Figure 11: Velocity Clamping5 Measured vs GT Distance

12

## 12 Ground Truth


Figure 12: Ground Truth Player Movement Path

13

## 13 Initial


Figure 13: Player Movement Path

14

## 14 Distance Correction0


Figure 14: Player Movement Path

15

## 15 Velocity Clamping1


Figure 15: Player Movement Path

16

## 16 Outlier Removal2


Figure 16: Player Movement Path

17

## 17 Kalman Filter3


Figure 17: Player Movement Path

18

## 18 EMA4


Figure 18: Player Movement Path

19

## 19 Velocity Clamping5


Figure 19: Player Movement Path

20

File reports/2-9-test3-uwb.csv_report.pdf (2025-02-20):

## Bluetooth Tracking Report

feb9/2-9-test3-uwb.csv

February 19, 2025

1

## 1 1D b1d_distance


Figure 1: b1d Distance Over Time

2

## 2 1D b2d_distance


Figure 2: b2d Distance Over Time

3

## 3 1D b3d_distance


Figure 3: b3d Distance Over Time

4

## 4 1D b4d_distance


Figure 4: b4d Distance Over Time

5

5 Initial - Ground Truth Comp.

Anchor 1: MAE=1.371 m, RMSE=1.464 m
Anchor 2: MAE=0.879 m, RMSE=1.587 m
Anchor 3: MAE=1.240 m, RMSE=2.685 m Anchor 4: MAE=2.447 m, RMSE=4.288 m


Figure 5: Initial Measured vs GT Distance

6

6 Distance Correction0 - Ground Truth Comp.

Anchor 1: MAE=0.694 m, RMSE=0.842 m
Anchor 2: MAE=1.363 m, RMSE=1.965 m
Anchor 3: MAE=1.184 m, RMSE=2.452 m Anchor 4: MAE=1.690 m, RMSE=3.887 m


Figure 6: Distance Correction0 Measured vs GT Distance

7

7 Velocity Clamping1 - Ground Truth Comp.

Anchor 1: MAE=0.694 m, RMSE=0.842 m
Anchor 2: MAE=1.636 m, RMSE=2.590 m
Anchor 3: MAE=1.184 m, RMSE=2.452 m Anchor 4: MAE=1.134 m, RMSE=2.796 m


Figure 7: Velocity Clamping1 Measured vs GT Distance

8

8 Outlier Removal2 - Ground Truth Comp.

Anchor 1: MAE=0.694 m, RMSE=0.842 m
Anchor 2: MAE=1.636 m, RMSE=2.590 m
Anchor 3: MAE=1.184 m, RMSE=2.452 m Anchor 4: MAE=1.134 m, RMSE=2.796 m


Figure 8: Outlier Removal2 Measured vs GT Distance

9

9 Kalman Filter3 - Ground Truth Comp.

Anchor 1: MAE=0.712 m, RMSE=0.848 m
Anchor 2: MAE=1.674 m, RMSE=2.684 m
Anchor 3: MAE=1.203 m, RMSE=2.460 m Anchor 4: MAE=1.141 m, RMSE=2.800 m


Figure 9: Kalman Filter3 Measured vs GT Distance

10

10 EMA4 - Ground Truth Comp.

Anchor 1: MAE=0.734 m, RMSE=0.884 m
Anchor 2: MAE=1.699 m, RMSE=2.785 m
Anchor 3: MAE=1.241 m, RMSE=2.448 m Anchor 4: MAE=1.162 m, RMSE=2.799 m


Figure 10: EMA4 Measured vs GT Distance

11

11 Velocity Clamping5 - Ground Truth Comp.

Anchor 1: MAE=0.734 m, RMSE=0.884 m
Anchor 2: MAE=1.699 m, RMSE=2.785 m
Anchor 3: MAE=1.241 m, RMSE=2.448 m Anchor 4: MAE=1.162 m, RMSE=2.799 m


Figure 11: Velocity Clamping5 Measured vs GT Distance

12

## 12 Ground Truth


Figure 12: Ground Truth Player Movement Path

13

## 13 Initial


Figure 13: Player Movement Path

14

## 14 Distance Correction0


Figure 14: Player Movement Path

15

## 15 Velocity Clamping1


Figure 15: Player Movement Path

16

## 16 Outlier Removal2


Figure 16: Player Movement Path

17

## 17 Kalman Filter3


Figure 17: Player Movement Path

18

## 18 EMA4


Figure 18: Player Movement Path

19

## 19 Velocity Clamping5


Figure 19: Player Movement Path

20

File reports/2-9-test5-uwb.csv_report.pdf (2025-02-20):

## Bluetooth Tracking Report

feb9/2-9-test5-uwb.csv

February 19, 2025

1

## 1 1D b1d_distance


Figure 1: b1d Distance Over Time

2

## 2 1D b2d_distance


Figure 2: b2d Distance Over Time

3

## 3 1D b3d_distance


Figure 3: b3d Distance Over Time

4

## 4 1D b4d_distance


Figure 4: b4d Distance Over Time

5

5 Initial - Ground Truth Comp.

Anchor 1: MAE=nan m, RMSE=nan m
Anchor 2: MAE=nan m, RMSE=nan m
Anchor 3: MAE=nan m, RMSE=nan m Anchor 4: MAE=nan m, RMSE=nan m


Figure 5: Initial Measured vs GT Distance

6

6 Distance Correction0 - Ground Truth Comp.

Anchor 1: MAE=nan m, RMSE=nan m
Anchor 2: MAE=nan m, RMSE=nan m
Anchor 3: MAE=nan m, RMSE=nan m Anchor 4: MAE=nan m, RMSE=nan m


Figure 6: Distance Correction0 Measured vs GT Distance

7

7 Velocity Clamping1 - Ground Truth Comp.

Anchor 1: MAE=nan m, RMSE=nan m
Anchor 2: MAE=nan m, RMSE=nan m
Anchor 3: MAE=nan m, RMSE=nan m Anchor 4: MAE=nan m, RMSE=nan m


Figure 7: Velocity Clamping1 Measured vs GT Distance

8

8 Outlier Removal2 - Ground Truth Comp.

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

Figure 8: Outlier Removal2 Measured vs GT Distance

9

9 Kalman Filter3 - Ground Truth Comp.

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


Figure 9: Kalman Filter3 Measured vs GT Distance

10

10 EMA4 - Ground Truth Comp.

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


Figure 10: EMA4 Measured vs GT Distance

11

11 Velocity Clamping5 - Ground Truth Comp.

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

Figure 11: Velocity Clamping5 Measured vs GT Distance

12

## 12 Ground Truth


Figure 12: Ground Truth Player Movement Path

13

## 13 Initial


Figure 13: Player Movement Path

14

## 14 Distance Correction0


Figure 14: Player Movement Path

15

## 15 Velocity Clamping1


Figure 15: Player Movement Path

16

## 16 Outlier Removal2


Figure 16: Player Movement Path

17

## 17 Kalman Filter3


Figure 17: Player Movement Path

18

## 18 EMA4


Figure 18: Player Movement Path

19

## 19 Velocity Clamping5


Figure 19: Player Movement Path

20

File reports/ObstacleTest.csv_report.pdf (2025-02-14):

## Bluetooth Tracking Report

ObstacleTest.csv

February 14, 2025

1

## 1 1D b1d_distance


Figure 1: b1d Distance Over Time

2

## 2 1D b2d_distance


Figure 2: b2d Distance Over Time

3

## 3 1D b3d_distance


Figure 3: b3d Distance Over Time

4

## 4 1D b4d_distance


Figure 4: b4d Distance Over Time

5

## 5 Initial - Ground Truth

Anchor 1: MAE=4.204 m, RMSE=7.727 m Anchor 2: MAE=4.398 m, RMSE=5.247 m Anchor 3: MAE=3.274 m, RMSE=4.804 m Anchor 4: MAE=3.726 m, RMSE=6.322 m


Figure 5: Initial Measured vs GT Distance

6

## 6 Distance Correction0 - Ground Truth

Anchor 1: MAE=4.204 m, RMSE=7.727 m
Anchor 2: MAE=4.398 m, RMSE=5.247 m
Anchor 3: MAE=3.274 m, RMSE=4.804 m Anchor 4: MAE=3.726 m, RMSE=6.322 m


Figure 6: Distance Correction0 Measured vs GT Distance

7

## 7 Outlier Removal1 - Ground Truth

Anchor 1: MAE=5.800 m, RMSE=13.003 m
Anchor 2: MAE=4.609 m, RMSE=5.636 m
Anchor 3: MAE=2.784 m, RMSE=3.614 m Anchor 4: MAE=4.382 m, RMSE=6.276 m


Figure 7: Outlier Removal1 Measured vs GT Distance

8

## 8 Kalman Filter2 - Ground Truth

Anchor 1: MAE=5.809 m, RMSE=13.037 m
Anchor 2: MAE=4.607 m, RMSE=5.643 m
Anchor 3: MAE=2.807 m, RMSE=3.661 m Anchor 4: MAE=4.399 m, RMSE=6.304 m


Figure 8: Kalman Filter2 Measured vs GT Distance

9

## 9 EMA3 - Ground Truth

Anchor 1: MAE=1.886 m, RMSE=2.509 m Anchor 2: MAE=4.189 m, RMSE=5.009 m Anchor 3: MAE=2.313 m, RMSE=3.097 m Anchor 4: MAE=3.777 m, RMSE=4.844 m


Figure 9: EMA3 Measured vs GT Distance

10

## 10 Distance Correction4 - Ground Truth

Anchor 1: MAE=1.886 m, RMSE=2.509 m
Anchor 2: MAE=4.189 m, RMSE=5.009 m
Anchor 3: MAE=2.313 m, RMSE=3.097 m Anchor 4: MAE=3.777 m, RMSE=4.844 m

Figure 10: Distance Correction4 Measured vs GT Distance

11

## 11 Initial


Figure 11: Player Movement Path

12

## 12 Distance Correction0


Figure 12: Player Movement Path

13

## 13 Outlier Removal1


Figure 13: Player Movement Path

14

## 14 Kalman Filter2


Figure 14: Player Movement Path

15

## 15 EMA3


Figure 15: Player Movement Path

16

## 16 Distance Correction4


Figure 16: Player Movement Path

17

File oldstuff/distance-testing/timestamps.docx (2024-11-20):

Stationary

10m - 10:05:31

20m - 10:06:05

30m - 10:06:39

40m - 10:07:12

50m - 10:07:44

60m - 10:08:16

Walk back from 60m - 10:08:36

Obstacles 10m

1person 10:20:17

2person 10:20:45

Clear 10:21:13

Obstacles 20m

1person 10:25:22

2person 10:25:42

clear 10:25:59

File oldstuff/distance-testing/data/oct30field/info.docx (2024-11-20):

for both 10m test, PRESS indicates person standing between equal spaced

for 20m test, press indicates person standingin between

for 2nd one, will went right next to responder. no press went off unfortunately, but should notice the spike in rssi and ftm

for the last 20m test, will started at 2m, walked closer to 1m, then walked back to 2m. Initial press, but no presses during. (distances are from responder)

For next 2 tests, paused for 20s after arriving.

For 1st 60m test

0: 10:43:40

10:10:43:58

20:10:44:37

30:10:45:18

40:10:45:56

50:10:46:33

50:10:47:10

then, started walking all the way back to the beacon

for 2nd 60m test

0:10:51:18

10:10:51:37

20:10:52:14

30:10:52:50

40:10:53:25

50:10:53:59

60:10:54:33

then started walking back

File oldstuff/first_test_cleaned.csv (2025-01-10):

timestamp | beacon1_dist | beacon2_dist | beacon3_dist
09:51:51.065 | 31.05 | 2.85 | 34.35
09:51:51.408 | 31.65 | 3.6 | 32.85
09:51:51.783 | 30.45 | 3.0 | 32.85
09:51:53.981 | 30.9 | 3.0 | 34.5
09:51:54.352 | 30.9 | 2.7 | 34.05
09:51:55.064 | 30.75 | 2.85 | 34.35
09:51:55.726 | 30.9 | 3.3 | 33.3
09:51:56.102 | 30.9 | 3.15 | 32.7
09:51:56.508 | 30.9 | 70.65 | 33.15
09:51:57.371 | 30.9 | 3.45 | 33.9
09:51:58.248 | 29.55 | 3.0 | 33.0
09:51:58.634 | 30.3 | 3.0 | 33.75
09:51:58.951 | 30.45 | 3.45 | 33.9
09:51:59.277 | 30.45 | 3.3 | 33.45
09:51:59.619 | 30.15 | 3.3 | 33.75
09:51:59.986 | 30.6 | 3.3 | 33.75
09:52:00.330 | 30.9 | 3.3 | 33.6
09:52:00.648 | 30.75 | 3.6 | 32.4
09:52:00.989 | 32.7 | 60.0 | 32.55
09:52:02.369 | 32.1 | 4.05 | 44.4
09:52:02.695 | 31.95 | 3.6 | 34.65
09:52:03.023 | 34.5 | 4.05 | 33.45
09:52:03.500 | 32.1 | 4.35 | 34.5
09:52:03.899 | 32.4 | 3.15 | 33.45
09:52:04.606 | 32.25 | 3.3 | 32.7
09:52:04.948 | 37.35 | 3.3 | 32.4
09:52:05.378 | 37.65 | 3.3 | 32.4
09:52:05.718 | 33.9 | 3.45 | 32.1
09:52:06.087 | 33.75 | 3.6 | 32.4
09:52:06.471 | 82.35 | 3.15 | 32.55
09:52:06.849 | 41.85 | 3.3 | 35.55
09:52:07.722 | 43.95 | 3.45 | 33.9
09:52:08.085 | 40.2 | 4.2 | 33.9
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

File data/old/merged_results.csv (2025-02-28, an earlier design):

timestamp | b3d_x | b4d_x | b2d_x | b1d_x | wearabletimestamp | b1d_y | b2d_y | b3d_y | b4d_y | xa | ya | za | ta | Error1 | Error2 | Error3 | Error4
1900-01-01 13:32:52 | 10.81665383 | 10.81665383 | 10.81665383 | 10.81665383 | 331608 | 10.741789815957365 | 10.938961416766755 | 10.784454593317584 | 19.680985600707274 | -1.1 | 9.73 | -1.29 | 1.6967616214424466 | -0.07486401404263532 | 0.12230758676675535 | -0.0321992366824162 | 8.864331770707274
1900-01-01 13:32:57 | 12.72792206 | 12.72792206 | 9.486832981 | 9.486832981 | 336616 | 9.003970533987612 | 8.970268776547826 | 13.208255128836777 | 12.90825323063195 | -0.71 | 9.81 | 1.22 | 1.411594842722231 | -0.482862447012387 | -0.5165642044521732 | 0.48033306883677795 | 0.18033117063195014
1900-01-01 13:33:03 | 10.81665383 | 15.0 | 12.36931688 | 6.708203932 | 342646 | 7.330679981612371 | 10.24017345700276 | 12.584657902664217 | 14.510555247742912 | 0.59 | 10.79 | -0.78 | 1.391617763611832 | 0.6224760496123709 | -2.12914342299724 | 1.7680040726642172 | -0.4894447522570875
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

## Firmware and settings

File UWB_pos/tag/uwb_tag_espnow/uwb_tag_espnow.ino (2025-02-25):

/*

For ESP32 UWB or ESP32 UWB Pro

*/
#include "WiFi.h"
#include "datastructures.h"
#include <esp_now.h>
#include <SPI.h>
#include <Wire.h>
#include <Adafruit_Sensor.h>
#include <Adafruit_ADXL345_U.h>
#include "DW1000Ranging.h"
// DW1000 makerfabs wiring:
#define SPI_SCK 18
#define SPI_MISO 19
#define SPI_MOSI 23
#define DW_CS 4

const int SEND_FREQ = 100;

// connection pins
const uint8_t PIN_RST = 27;  // reset pin
const uint8_t PIN_IRQ = 34;  // irq pin
const uint8_t PIN_SS = 4;    // spi select pin
const uint8_t PIN_SDA = 21;
const uint8_t PIN_SCL = 22;

Adafruit_ADXL345_Unified accel = Adafruit_ADXL345_Unified(12345);


// NOTE: change the broadcastAddress to the mac address of the recorder beacon
// to find the recorder address, uncomment the readMacAddress() function in setup(), then insert it here in the following format
// const uint8_t broadcastAddress[] = { 0x64, 0xE8, 0x33, 0x50, 0xC3, 0xf8 }; //prev recorder beacon address
const uint8_t broadcastAddress[] = { 0xf0, 0x9e, 0x9e, 0x3b, 0xe5, 0xd8 };
esp_now_peer_info_t peerInfo;

// ---------------- DWM1000 wiring -----------------------:
// #define SPI_SCK 8
// #define SPI_MISO 9
// #define SPI_MOSI 10
// #define DW_CS 2
// const uint8_t PIN_RST = 5;
// const uint8_t PIN_IRQ = 3;
// const uint8_t PIN_SS = 2;
// - use instead of above defs if using "homemade board" -

Message curData;
u_int32_t lastSent = 0;

void OnDataSent(const uint8_t *mac_addr, esp_now_send_status_t status) {
  // Debug
  // Serial.print("\r\nLast Packet Send Status:\t");
  // Serial.println(status == ESP_NOW_SEND_SUCCESS ? "Delivery Success" : "Delivery Fail");
  return;
}



void setup() {
  curData.playerID = 'b';
  Serial.begin(115200);
  delay(1000);
  // Debugging with no accel
  Wire.begin(PIN_SDA, PIN_SCL);
  accel.begin();
  accel.setRange(ADXL345_RANGE_16_G);

  //init the configuration
  SPI.begin(SPI_SCK, SPI_MISO, SPI_MOSI);
  WiFi.mode(WIFI_STA);
  if (esp_now_init() != ESP_OK) {
    Serial.println("Error initializing ESP-NOW");
    return;
  }
  esp_now_register_send_cb(OnDataSent);

  // Register peer
  memcpy(peerInfo.peer_addr, broadcastAddress, 6);
  peerInfo.channel = 0;
  peerInfo.encrypt = false;

  // Add peer
  if (esp_now_add_peer(&peerInfo) != ESP_OK) {
    // Debug
    Serial.println("Failed to add peer");
    return;
  }

  DW1000Ranging.initCommunication(PIN_RST, PIN_SS, PIN_IRQ);  //Reset, CS, IRQ pin
  DW1000Ranging.attachNewRange(newRange);
  DW1000Ranging.attachNewDevice(newDevice);
  DW1000Ranging.attachInactiveDevice(inactiveDevice);
  //Set as tag
  DW1000Ranging.startAsTag("7D:00:22:EA:82:60:3B:9C", DW1000.MODE_LONGDATA_RANGE_LOWPOWER); //tag1-potentially investigate new modes
  // DW1000Ranging.startAsTag("99:99:88:88:66:11:25:32", DW1000.MODE_LONGDATA_RANGE_LOWPOWER);  //tag2
}

void loop() {

  DW1000Ranging.loop();

  if ((millis() - lastSent) > SEND_FREQ) {
    //   // Debug
    //   Serial.print(millis());
    //   Serial.print(',');
    //   Serial.print(curData.CollectedBeaconData[0].dist);
    //   Serial.print(',');
    //   Serial.print(curData.CollectedBeaconData[1].dist);
    //   Serial.print(',');
    //   Serial.print(curData.CollectedBeaconData[2].dist);
    //   Serial.print(',');
    //   Serial.print(curData.CollectedBeaconData[3].dist);
    //   Serial.print(',');
    //   Serial.print(event.acceleration.x);
    //   Serial.print(',');
    //   Serial.print(event.acceleration.y);
    //   Serial.print(',');
    //   Serial.print(event.acceleration.z);
    //   Serial.println();
    sensors_event_t event;
    accel.getEvent(&event);
    curData.xaccel = (int)(event.acceleration.x * 100.0);
    curData.yaccel = (int)(event.acceleration.y * 100.0);
    curData.zaccel = (int)(event.acceleration.z * 100.0);
    curData.timestamp = millis();
    esp_err_t result = esp_now_send(broadcastAddress, (uint8_t *)&curData, sizeof(curData));  // sending our message to the recorder beacon via espnow
    // delay(30);
    // Serial.print(result);
    // result = esp_now_send(broadcastAddress, (uint8_t *)&curData, sizeof(curData));  // redundancy message. won't actually be printed, as only novel timestamps are printed
    lastSent = millis();
  }
  // esp_err_t result = esp_now_send(broadcastAddress, (uint8_t *)&curData, sizeof(curData));  // sending our message to the recorder beacon via espnow
}

void newRange() {
  // Serial.println("pinged!");
  u_int16_t address = DW1000Ranging.getDistantDevice()->getShortAddress();
  switch (address) {
    case 0x1786:
      curData.CollectedBeaconData[0].dist = (int)(DW1000Ranging.getDistantDevice()->getRange() * 100);
      curData.CollectedBeaconData[0].rssi = (int)(DW1000Ranging.getDistantDevice()->getRXPower() * 100);
      break;

    case 0x2222:
      curData.CollectedBeaconData[1].dist = (int)(DW1000Ranging.getDistantDevice()->getRange() * 100);
      curData.CollectedBeaconData[1].rssi = (int)(DW1000Ranging.getDistantDevice()->getRXPower() * 100);
      break;

    case 0x2897:
      curData.CollectedBeaconData[2].dist = (int)(DW1000Ranging.getDistantDevice()->getRange() * 100);
      curData.CollectedBeaconData[2].rssi = (int)(DW1000Ranging.getDistantDevice()->getRXPower() * 100);
      break;

    case 0x4444:
      curData.CollectedBeaconData[3].dist = (int)(DW1000Ranging.getDistantDevice()->getRange() * 100);
      curData.CollectedBeaconData[3].rssi = (int)(DW1000Ranging.getDistantDevice()->getRXPower() * 100);
      break;


    default:
      Serial.print("from: ");
      Serial.print(DW1000Ranging.getDistantDevice()->getShortAddress());
      Serial.print("\t Range: ");
      Serial.print(DW1000Ranging.getDistantDevice()->getRange());
      Serial.print(" m");
      Serial.print("\t RX power: ");
      Serial.print(DW1000Ranging.getDistantDevice()->getRXPower());
      Serial.println(" dBm");
  }
}

void newDevice(DW1000Device *device) {
  Serial.print("ranging init; 1 device added ! -> ");
  Serial.print(" short:");
  Serial.println(device->getShortAddress(), HEX);
}

void inactiveDevice(DW1000Device *device) {
  Serial.print("delete inactive device: ");
  Serial.println(device->getShortAddress(), HEX);
}

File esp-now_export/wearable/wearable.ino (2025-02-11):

/* Based on Wi-Fi FTM Initiator Arduino Example
 *
 *   This example code is in the Public Domain (or CC0 licensed, at your option.)
 *
 *   Unless required by applicable law or agreed to in writing, this
 *   software is distributed on an "AS IS" BASIS, WITHOUT WARRANTIES OR
 *   CONDITIONS OF ANY KIND, either express or implied.
 */
#include "WiFi.h"
#include <esp_now.h>
#include <Wire.h>
#include <Adafruit_Sensor.h>
#include <Adafruit_ADXL345_U.h>
#include "dataStructures.h"

Adafruit_ADXL345_Unified accel = Adafruit_ADXL345_Unified(12345);  // ensure board target is set to xiao_esp32s3, or else the I2C pins may be incorrect
/*
 *   THIS FEATURE IS SUPPORTED ONLY BY ESP32-S2 AND ESP32-C3
 */

// Beacon number and names -- assumes no password to connect
int numBeacons = 4;
const char *beacons[4] = { "beacon1", "beacon2", "beacon3", "beacon4" };


// FTM settings
// Number of FTM frames requested in terms of 4 or 8 bursts (allowed values - 0 (No pref), 16, 24, 32, 64)
const uint8_t FTM_FRAME_COUNT = 8;  //default 16
// Requested time period between consecutive FTM bursts in 100’s of milliseconds (allowed values - 0 (No pref) or 2-255)
const uint16_t FTM_BURST_PERIOD = 2;

// Semaphore to signal when FTM Report has been received
SemaphoreHandle_t ftmSemaphore;
// Status of the received FTM Report
bool ftmSuccess = true;
// bool received = false;

unsigned long startConnectTime;
int connectTimeOut = 150;  //time in ms that we will try connecting for.

BeaconData curValues;
Message curMessage;

const uint8_t broadcastAddress[] = { 0x64, 0xE8, 0x33, 0x50, 0xC3, 0xf8 };

esp_now_peer_info_t peerInfo;

void OnDataSent(const uint8_t *mac_addr, esp_now_send_status_t status) {
  // Debugging:
  // Serial.print("\r\nLast Packet Send Status:\t");
  // Serial.println(status == ESP_NOW_SEND_SUCCESS ? "Delivery Success" : "Delivery Fail");
  return;
}

// FTM report handler with the calculated data from the round trip
// WARNING: This function is called from a separate FreeRTOS task (thread)!
void onFtmReport(arduino_event_t *event) {
  const char *status_str[5] = { "SUCCESS", "UNSUPPORTED", "CONF_REJECTED", "NO_RESPONSE", "FAIL" };
  wifi_event_ftm_report_t *report = &event->event_info.wifi_ftm_report;
  // Set the global report status
  ftmSuccess = report->status == FTM_STATUS_SUCCESS;
  if (ftmSuccess) {
    // The estimated distance in meters may vary depending on some factors (see README file)
    // Serial.printf("[%.2f,%lu,%d]", (float)report->dist_est / 100.0, report->rtt_est,WiFi.RSSI());
    curValues.FTMdist = report->dist_est;
    curValues.rssi = WiFi.RSSI();
    // Pointer to FTM Report with multiple entries, should be freed after use
    free(report->ftm_report_data);
    WiFi.disconnect();  //TODO: evaluate importance of these disconnect calls within callback; don't think they're necessary
                        // received = true;
  } else {
    // Serial.print("[FTMErr");
    // Serial.print(status_str[report->status]);
    // Serial.print(']');
    WiFi.disconnect(); 
  }
  // Signal that report is `ed
  xSemaphoreGive(ftmSemaphore);
}

// Initiate FTM Session and wait for FTM Report
bool getFtmReport() {
  if (!WiFi.initiateFTM(FTM_FRAME_COUNT, FTM_BURST_PERIOD)) {
    Serial.print("\"FTM Error: Initiate Session Failed\"");
    return false;
  }
  // Wait for signal that report is received and return true if status was success
  return xSemaphoreTake(ftmSemaphore, portMAX_DELAY) == pdPASS && ftmSuccess;
}

void setup() {
  Serial.begin(115200);
  accel.begin();
  accel.setRange(ADXL345_RANGE_16_G);

  WiFi.mode(WIFI_STA);
  // Create binary semaphore (initialized taken and can be taken/given from any thread/ISR)
  ftmSemaphore = xSemaphoreCreateBinary();

  // Will call onFtmReport() from another thread with FTM Report events.
  WiFi.onEvent(onFtmReport, ARDUINO_EVENT_WIFI_FTM_REPORT);

  if (esp_now_init() != ESP_OK) {
    Serial.println("Error initializing ESP-NOW");
    return;
  }
  esp_now_register_send_cb(OnDataSent);

  // Register peer
  memcpy(peerInfo.peer_addr, broadcastAddress, 6);
  peerInfo.channel = 0;
  peerInfo.encrypt = false;

  // Add peer
  if (esp_now_add_peer(&peerInfo) != ESP_OK) {
    // Debug
    // Serial.println("Failed to add peer");
    return;
  }
}

void loop() {
  for (int i = 0; i < numBeacons; i++) {
    sensors_event_t event;
    accel.getEvent(&event);
    startConnectTime = millis();
    // TODO: add method that sets all curValues to default, then call it here. This way, failed readings can be deciphered.
    curMessage.xaccel = (int16_t)(event.acceleration.x * 100);
    curMessage.yaccel = (int16_t)(event.acceleration.y * 100);
    curMessage.zaccel = (int16_t)(event.acceleration.z * 100);
    WiFi.begin(beacons[i], NULL);
    while ((WiFi.status() != WL_CONNECTED) && (millis() - startConnectTime) < connectTimeOut) {  // wait is this wrong?
      delay(10);
    }
    if (WiFi.status() == WL_CONNECTED) {
      getFtmReport();
      // curValues.timestamp = millis();

      //Now, we update our message. Specifically, we update the data corresponding to the beacon.
      curMessage.CollectedBeaconData[i].FTMdist = curValues.FTMdist;
      WiFi.disconnect();
    } else {
      WiFi.disconnect();
    }
  }
  curMessage.timestamp = millis();
  // Output for debugging:
  // Serial.printf("%lu,%d,%d,%d,%d,%d,%d,%d",curMessage.timestamp,curMessage.CollectedBeaconData[0].FTMdist,curMessage.CollectedBeaconData[1].FTMdist,curMessage.CollectedBeaconData[2].FTMdist,curMessage.CollectedBeaconData[3].FTMdist,
  //                 curMessage.xaccel,curMessage.yaccel,curMessage.zaccel); //note: currently, not reporting RSSI, but this could be added in the future
  //   Serial.println();
  
  esp_err_t result = esp_now_send(broadcastAddress, (uint8_t *)&curMessage, sizeof(curMessage));  // sending our message to the recorder beacon via espnow
  delay(30);
  result = esp_now_send(broadcastAddress, (uint8_t *)&curMessage, sizeof(curMessage));  // redundancy message. won't actually be printed, as only novel timestamps are printed
}

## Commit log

2024-09-26 get light to switch color on button press
2024-11-01 made a bunch of plots
    [10m obstacle test 2_cleaned.csv, 10m obstacle test_cleaned.csv, 20m 1 obstacle moving away_cleaned.csv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]
2024-11-20 initial kalman filter and some data
    [oct14fmt.csv, oct14realdistance.csv]
2024-11-23 new outlier removal begininnings, new data cleaner
    [first_test_cleaned.csv]
2025-01-10 initial look at kalman filtering
2025-01-14 more kalman filter
2025-01-20 fixed accel, fixed delay bug, updated message struct
    [recorder_beacon.ino, wearable.ino]
2025-01-20 more kalman stuff
    [beaconv1.csv, beaconv2.csv, groundtruth-plus.csv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]
2025-01-24 Added csv to load into PD DF for Sam
    [4beaconv1.csv]
2025-01-24 Reorganized file structure. All pipeline things work with the final- files
    [first_test_cleaned.csv]
2025-01-27 updated abs_error and moved smoothed data
    [4beaconv1.csv]
2025-01-31 Added Sam's stuff to pipeline
    [4beaconv1.csv, GroundyTruthy.csv, merged_results.csv]
2025-02-03 acceleration magnitude work
    [smallsquare.csv]
2025-02-05 added groundtruth interpolation
    [jan17-groundtruth.csv]
2025-02-05 file re-org
    [first_test_cleaned.csv]
2025-02-06 added prototype UWB firmware
2025-02-06 initial kalman tuning
    [standing still.csv]
2025-02-11 new testing data and cleanup fcn
    [2-9-test3-groundtruth.csv, 2-9-test3-uwb.csv]
2025-02-11 minor fixes
    [2-9-test3-ftm.csv]
2025-02-12 some cleanup
    [2-9-standstill-ftm.csv, 2-9-test3-ftm.csv, 2-9-test3-groundtruth.csv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]
2025-02-12 espnow tag and test5(feb9) data
    [2-9-test5-ftm.csv, 2-9-test5-uwb.csv]
2025-02-14 Added report functionality
    [merged_results.csv, rawdataexample.csv]
2025-02-14 commit to pull
    [GT-obstacletest-UWB-feb5.csv, GT-overheadtest-UWB-feb5.csv, ObstacleTest.csv]
2025-02-14 added switch to generate pdf so it won't cause error hopefully
2025-02-18 Added ground truth 2d plot to report and charts
    [merged_results.csv]
2025-02-19 Gen reports for uwb vs ftm, made plots for abs error optional
    [merged_results.csv]
2025-02-19 fixed espnow export for UWB and made compatible w/ recorder
    [recorder_beacon.ino, uwb_tag_espnow.ino]
2025-02-19 tried making a prediction model for x,y and added some additional data collection to pipeline
    [merged_player_positions.csv, merged_results.csv, player_positions_Distance Correction0.csv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]
2025-02-20 added the "Impossible circle"
    [merged_results.csv, player_positions_Distance Correction0.csv, player_positions_EMA4.csv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]
2025-02-20 some work on new trilateration
    [processedtest.csv, processedtest1.csv, processedtest6.csv]
2025-02-21 made y axis for abserror subplots shared
2025-02-21 fixed feb9 groundtruth error
    [2-9-test3-groundtruth.csv]
2025-02-21 added y axis limit for gt comp plots
2025-02-24 2d filtering updates
2025-02-24 changed what gets plotted
    [merged_results.csv, player_positions_Distance Correction0.csv, player_positions_EMA4.csv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]
2025-02-25 more kalman stuff and velocity clamping
2025-02-25 added t1-aroundsquare-groundtruth
2025-02-25 minor fix
    [t1-aroundsquare-groundtruth.csv]
2025-02-25 added t2-diagonals-groundtruth.csv
    [t2-diagonals-groundtruth.csv]
2025-02-26 plotting ground truth again
2025-02-28 final version of frontend works! other updates
    [merged_results.csv, player_positions_Distance Correction0.csv, player_positions_EMA4.csv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]
2025-02-28 added animation to the frontend
    [player_positions_streamlit.csv]
2025-02-28 added streamlit stuff, thought I pushed last night
    [player_positions_streamlit.csv]
2025-03-15 Update and rename analyze_ftm_data.py to GroundTruthPipeline.py
2025-03-15 added old data
    [2mObstacleTest.csv, 4beaconv1.csv, ChestTest.csv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]
2025-03-15 organized data folder
    made folders with readmes for each testing day and put the data inside
    [2-9-standstill-ftm.csv, 2-9-test5-ftm.csv, 2-9-test5-uwb.csv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]
2025-03-15 Update and rename GroundTruthPipeline.py to analyze_ftm_data.py
2025-03-16 Rename iPod_Tripod_Mount_repaired (1).stl to haasebert _iPod_Tripod_Mount.stl
    [haasebert _iPod_Tripod_Mount.stl]
2025-03-16 Rename haasebert _iPod_Tripod_Mount.stl to haasebert_iPod_Tripod_Mount.stl
    [haasebert_iPod_Tripod_Mount.stl]
2025-03-16 added individual readmes for FTM/UWB. Formatting fixes in sketches
    [anchor.ino, wearable_espnow.ino]
2025-03-16 Rename iPod_Tripod_Mount_repaired (2).stl to iPod_Tripod_Mount_repaired.stl
    [iPod_Tripod_Mount_repaired.stl]
2025-03-17 added wearable files and FTM beacons
    [FTM_beacon.step, UWB_clip_mount.step]
2025-03-17 reorganized everything. Looks brand new.
    [10m obstacle test 2_cleaned.csv, 10m obstacle test_cleaned.csv, 20m 1 obstacle moving away_cleaned.csv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]
